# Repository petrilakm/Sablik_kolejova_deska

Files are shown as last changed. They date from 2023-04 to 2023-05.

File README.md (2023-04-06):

# sablik kolejova deska

připojení originální kolejové desky k hJOP pro indikace z modelového kolejiště.
Kolejová deska se chová jako virtuální vyhýbky na sběrnici XpressNET

pro komunikaci s XpressNETem je vytvořena knihovna, která komunikuje
s centrálou jako ovladač LH100.

Panel je jednoúčelový

Control panel for railway switch operation via XpressNET (NX)
tested on Lenz LZV100 and Paco's NanoX. Panel send messages same way as hand controller LH100.
Used microcontroller is ATmega328 (Arduino Nano) and SPI communication with 74HC595 and 74HC165 expanders,
but code can be easily deployed to other AVR family controllers.

On XpressNET there is many virtual switches, which are indicated on real outputs.
Control program (hJOP) sets this virtual switches via python API.

This control panel is only for one purpouse. All changes must be done in source code.

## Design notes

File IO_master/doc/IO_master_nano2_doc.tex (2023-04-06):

\documentclass[a4paper]{report}
\usepackage[landscape]{geometry}
\usepackage{graphicx,color}%,fig}
 \usepackage[czech]{babel}
\setlength{\textheight}{29cm}
\setlength{\textwidth}{20cm}
\pagestyle{empty}
\setlength{\unitlength}{1mm}

%\newcommand{\ram}{
\begin{document}
\begin{picture}(0,0)(50,180)
%\linethickness{0.1pt}
%[angle=90]

%\put(-4,28){\framebox(173,248)}
%\put(-10,10){\mbox{IO\_master -  řídící modul pro kolejovou desku (16. 12. 2022) }}

\put(20,123){}
\put(60,123){}
\put(100,123){}
\put(0,0){}

\end{picture}

\end{document}

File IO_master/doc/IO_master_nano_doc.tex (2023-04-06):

\documentclass[a4paper]{report}
\usepackage{graphicx,color}%,fig}
 \usepackage[czech]{babel}
\setlength{\textheight}{29cm}
\setlength{\textwidth}{20cm}
\pagestyle{empty}
\setlength{\unitlength}{1mm}

%\newcommand{\ram}{
\begin{document}
\begin{picture}(100,140)(23,150)
%\linethickness{0.1pt}
%[angle=90]

%\put(-4,28){\framebox(173,248)}
\put(-10,310){\mbox{IO\_master -  řídící modul pro kolejovou desku (29. 10. 2022) }}
\put(-20,20){}
\put(20,20){}
\put(70,20){}

\end{picture}

\end{document}

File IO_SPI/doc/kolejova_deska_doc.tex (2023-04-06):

\documentclass[a4paper]{report}
%\usepackage{graphicx,color}%,fig}
%\usepackage[czech]{babel}
\usepackage[top=2cm, bottom=2cm, left = 2cm, right = 2cm]{geometry} 
\usepackage{tikz}
%\usepackage{showframe}
%\setlength{\textheight}{29cm}
%\setlength{\textwidth}{18cm}
\setlength{\unitlength}{1mm}
%\title{Kolejová deska}

\begin{document}
kolejová deska Výstupy:

\vspace{7cm}

kolejová deska Vstupy:

\newcommand{\jmi}{RPi_SPI_outputs_v04}
\newcommand{\jmo}{RPi_SPI_inputs_v04}

\vspace{8cm}
\begin{tikzpicture}
%\linethickness{0.1pt}
%[angle=90]
%\put(0,0){\framebox(100,100)}
\put(0,90){}
\put(60,90){}
\put(0,0){}
\put(60,0){}
\end{tikzpicture}
%\end{picture}

Výstupy:

1x 100n 1206

1x 0R 1206

2x DIL16 (75HC595)

3x drátová propojka

\vspace{1cm}

Vstupy:

1x 100n 1206

2x DIL16 (75HC165)

2x rezistorová síť 8x10k

4x drátová propojka

\end{document}

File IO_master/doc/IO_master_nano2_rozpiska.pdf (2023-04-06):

Qty | Value | Parts
1 | | ARDUINO_NANO1
2 | MA08-01 | SV2, SV5
1 | 1N4007-SMD | D1
1 | 47u/25V | C4
1 | 78L05F | IC2
3 | 100n | C1, C2, C3
1 | MAX485 | IC1
1 | WEBP6-6 | J1

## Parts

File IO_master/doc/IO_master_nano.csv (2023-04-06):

Qty | Value | Device | Parts
1 |  | ARDUINO_NANO_2 | ARDUINO_NANO1
2 |  | MA08-1 | SV2, SV5
1 | 1N4007-SMD | 1N4007-SMD | D1
1 | 47u/25V | CPOL-EUE2.5-6L | C4
1 | 78L05F | 78L05F | IC2
3 | 100n | C-EUC1206 | C1, C2, C3
1 | 75176-SO | 75176-SO | IC1
4 | MOUNT-PAD-ROUND3.2 | MOUNT-PAD-ROUND3.2 | H1, H2, H3, H4
1 | WEBP6-6_SPEC2 | WEBP6-6_SPEC2 | J1

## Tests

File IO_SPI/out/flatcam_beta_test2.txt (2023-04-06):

; load
open_gerber z:\petrilak.m\Elektronika\Projekty\KMZ\Doplnky\Sablik_kolejova_deska\IO_SPI\brd\RPi_SPI_inputs_v04.bot.grb -outname bot
set_sys excellon_zeros T
open_excellon z:\petrilak.m\Elektronika\Projekty\KMZ\Doplnky\Sablik_kolejova_deska\IO_SPI\brd\RPi_SPI_inputs_v04.exc  -outname drl
plot_all

; export etch
isolate bot -dia 0.22 -passes 3 -overlap 30 -combine 1 -outname iso
cncjob iso -z_cut -0.08 -z_move 1.2 -feedrate 240 -feedrate_z 120 -dia 0.2 -spindlespeed 30000 -outname etch
write_gcode etch z:/petrilak.m/Elektronika/Projekty/KMZ/Doplnky/Sablik_kolejova_deska/IO_SPI/out/inputs_v04_etch.nc

; export drill
drillcncjob drl -drillz -3 -travelz 1 -feedrate_z 200 -toolchangez 15.0 -endxy (-20.0,20.0) -toolchangexy (-20.0,20.0) -dwelltime 0.1 -diatol 5 -outname drills

; export outline
open_gerber z:\\petrilak.m\\Elektronika\\Projekty\\KMZ\\Doplnky\\Sablik_kolejova_deska\\IO_SPI\\brd\\RPi_SPI_inputs_v04.out.grb -outname outline
follow outline -outname outline_geo
cutout outline_geo -dia 2.0 -margin 0.1 -gapsize 0.5 -gaps lr -outname out_cnc
cncjob out_cnc -z_cut -2.0 -dpp 0.7 -z_move 1.2 -feedrate 100 -feedrate_z 60 -dia 2 -spindlespeed 30000 -outname out
write_gcode out z:/petrilak.m/Elektronika/Projekty/KMZ/Doplnky/Sablik_kolejova_deska/IO_SPI/out/inputs_v04_out.nc

interiors
milldrills drl -milled_dias "3.2" -tooldia 2.0 -diatol 50 -outname drlmill

millholes drl -tools 5 -tooldia 2.0 -outname drlmill
cutout bot -dia 2.0 -margin 0.1 -gapsize 0.5 -gaps 4

drillcncjob
cncjob iso
cncjob iso

// merge
new
set_sys excellon_zeros T
open_excellon z:/petrilak.m/Elektronika/Projekty/KMZ/Doplnky/Sablik_kolejova_deska/IO_SPI/brd/RPi_SPI_outputs_v04.txt -outname drl1
open_excellon z:/petrilak.m/Elektronika/Projekty/KMZ/Doplnky/Sablik_kolejova_deska/IO_SPI/brd/RPi_SPI_outputs_v04.txt -outname drl2
offset drl2 0 44
join_excellons drl drl1 drl2

open_gerber z:/petrilak.m/Elektronika/Projekty/KMZ/Doplnky/Sablik_kolejova_deska/IO_SPI/brd/RPi_SPI_outputs_v04.bot -outname bot1
open_gerber z:/petrilak.m/Elektronika/Projekty/KMZ/Doplnky/Sablik_kolejova_deska/IO_SPI/brd/RPi_SPI_outputs_v04.bot -outname bot2
offset bot2 0 44

open_gerber z:/petrilak.m/Elektronika/Projekty/KMZ/Doplnky/Sablik_kolejova_deska/IO_SPI/brd/RPi_SPI_outputs_v04.out -outname outline1
open_gerber z:/petrilak.m/Elektronika/Projekty/KMZ/Doplnky/Sablik_kolejova_deska/IO_SPI/brd/RPi_SPI_outputs_v04.out -outname outline2
offset outline2 0 44
follow outline1 -outname outline_geo1
follow outline2 -outname outline_geo2
join_geometry outline outline_geo1 outline_geo2 
cncjob outline -z_cut -2.6 -z_move 1.2 -feedrate 100 -feedrate_z 60 -dia 2 -spindlespeed 30000 -outname holes

isolate bot1 -dia 0.18 -passes 4 -overlap 5 -combine 1 -outname iso1
isolate bot2 -dia 0.18 -passes 4 -overlap 5 -combine 1 -outname iso2
join_geometries iso iso1 iso2

milldrills drl -milled_dias 3.2 -tooldia 2.0 -diatol 50 -outname drlmill
millholes drl -tooldia 2.0 -outname drlmill

cutout outline_geo -dia 2.0 -margin 0.1 -gapsize 0.5 -gaps lr -outname out1
cutout outline_geo2 -dia 2.0 -margin 0.1 -gapsize 0.5 -gaps lr -outname out2
join_geometry out out1 out2
cncjob out -z_cut -2.6 -z_move 1.2 -endz 10.0 -feedrate 100 -feedrate_z 60 -dia 2 -spindlespeed 30000 -dpp 0.7 -outname outa
write_gcode out z:/petrilak.m/Elektronika/Projekty/KMZ/Doplnky/Sablik_kolejova_deska/IO_SPI/out/out.nc

drillcncjob drl -drillz -3 -travelz 1 -feedrate_z 200 -toolchangez 15.0 -endxy (20.0,-20.0) -dwelltime 0.1 -diatol 5 -outname drills
cncjob iso -z_cut -0.08 -z_move 1.2 -feedrate 240 -feedrate_z 120 -dia 0.2 -spindlespeed 30000 -outname etch
write_gcode etch z:/petrilak.m/Elektronika/Projekty/KMZ/Doplnky/Sablik_kolejova_deska/IO_SPI/out/etch.nc
write_gcode drills z:/petrilak.m/Elektronika/Projekty/KMZ/Doplnky/Sablik_kolejova_deska/IO_SPI/out/drills.nc
write_gcode drl_cnc z:/petrilak.m/Elektronika/Projekty/KMZ/Doplnky/Sablik_kolejova_deska/IO_SPI/out/drills.nc

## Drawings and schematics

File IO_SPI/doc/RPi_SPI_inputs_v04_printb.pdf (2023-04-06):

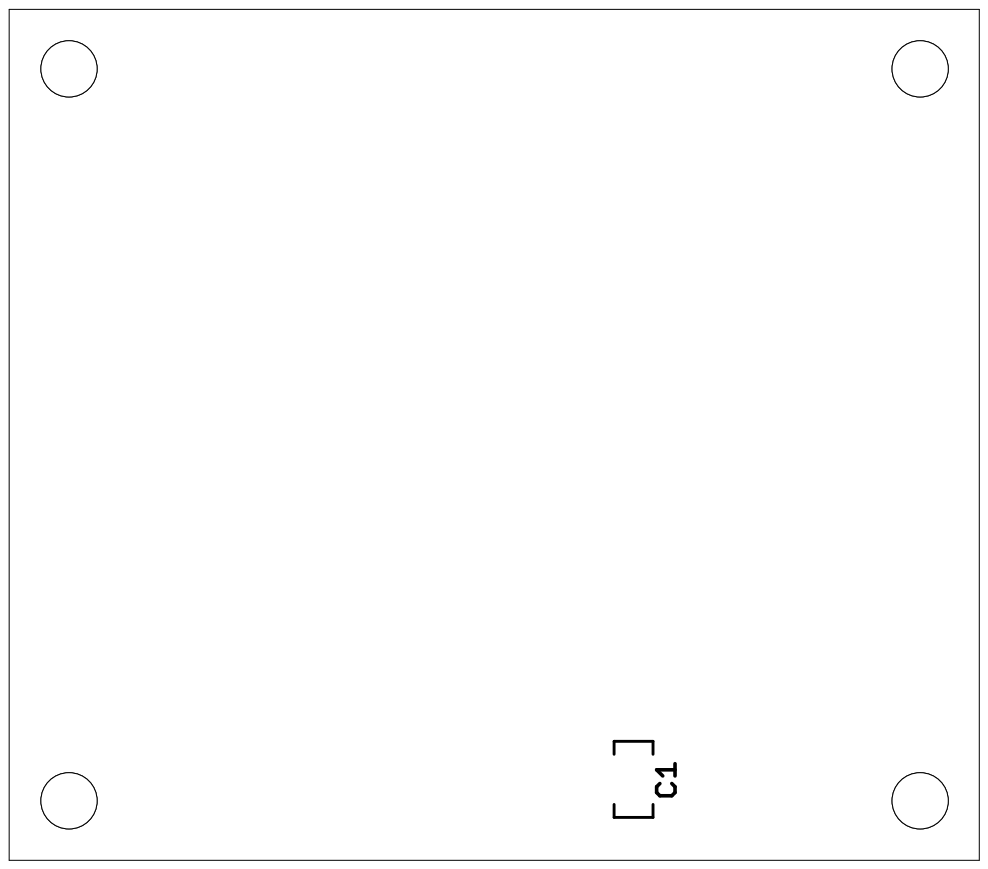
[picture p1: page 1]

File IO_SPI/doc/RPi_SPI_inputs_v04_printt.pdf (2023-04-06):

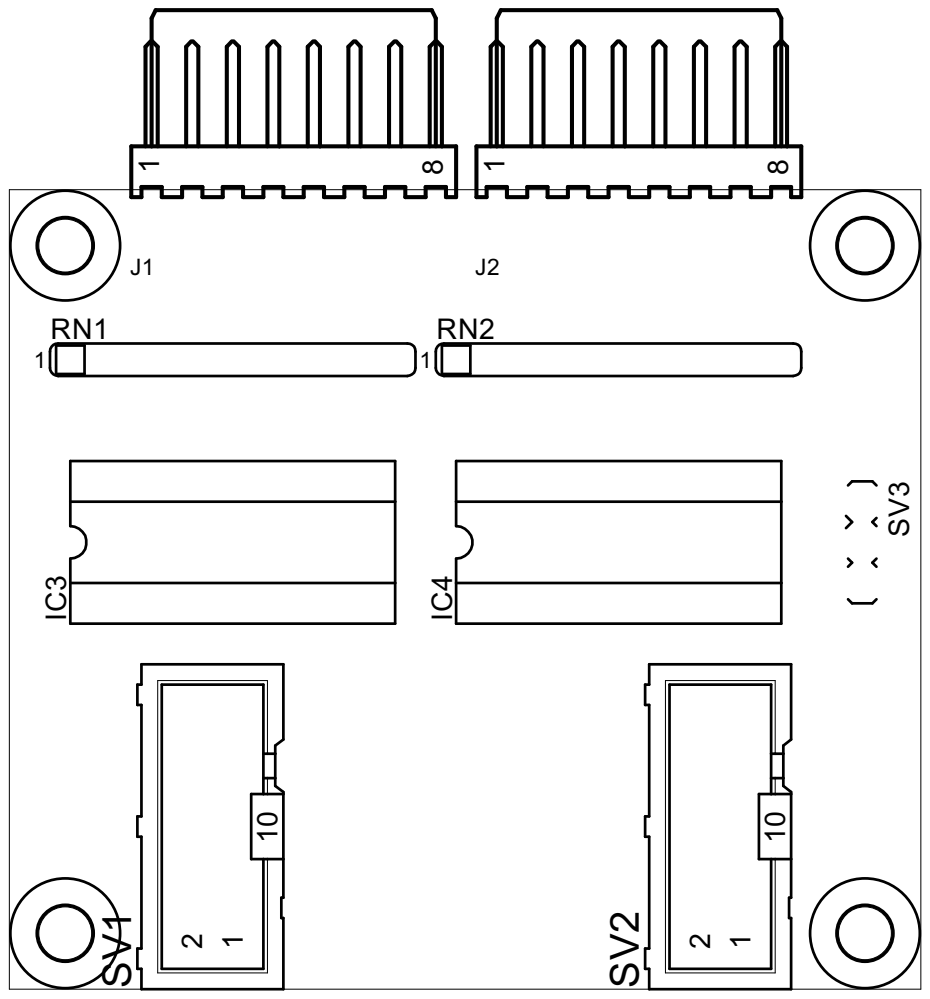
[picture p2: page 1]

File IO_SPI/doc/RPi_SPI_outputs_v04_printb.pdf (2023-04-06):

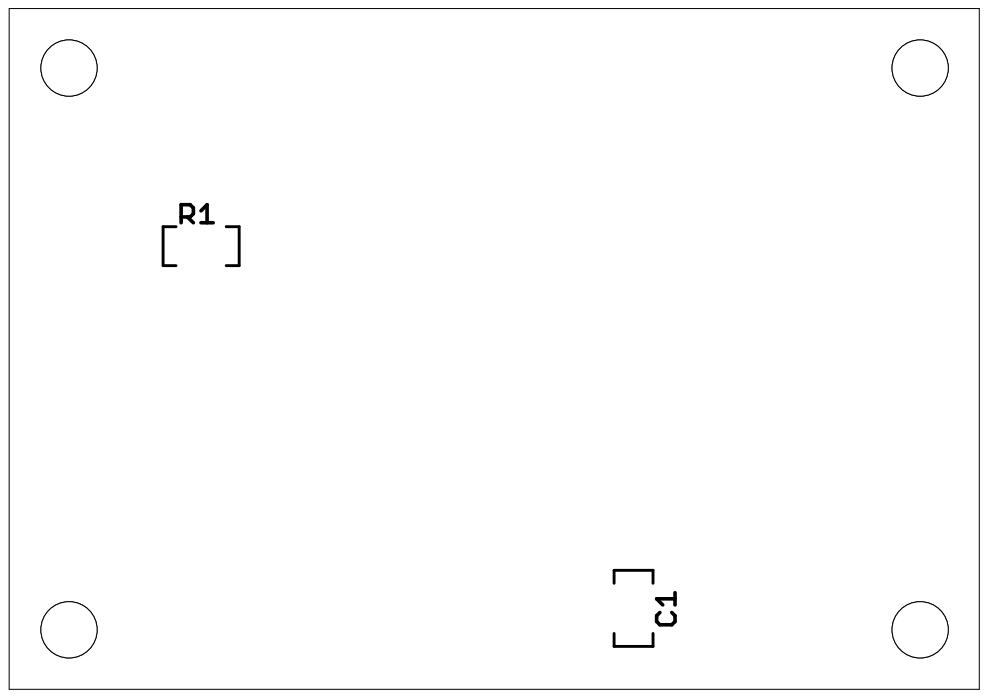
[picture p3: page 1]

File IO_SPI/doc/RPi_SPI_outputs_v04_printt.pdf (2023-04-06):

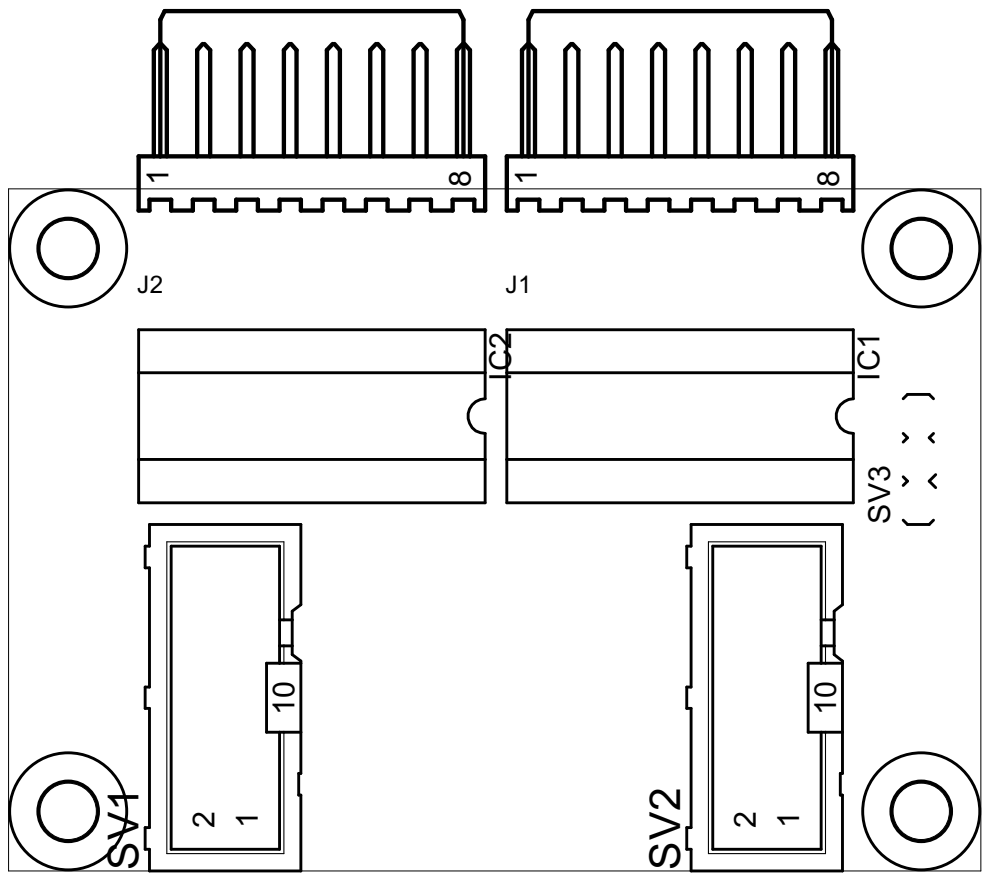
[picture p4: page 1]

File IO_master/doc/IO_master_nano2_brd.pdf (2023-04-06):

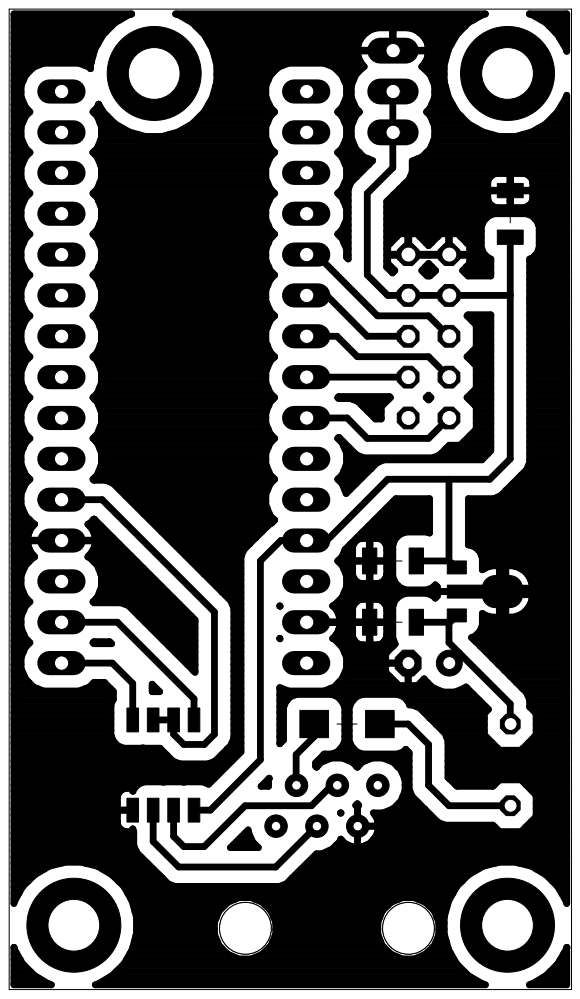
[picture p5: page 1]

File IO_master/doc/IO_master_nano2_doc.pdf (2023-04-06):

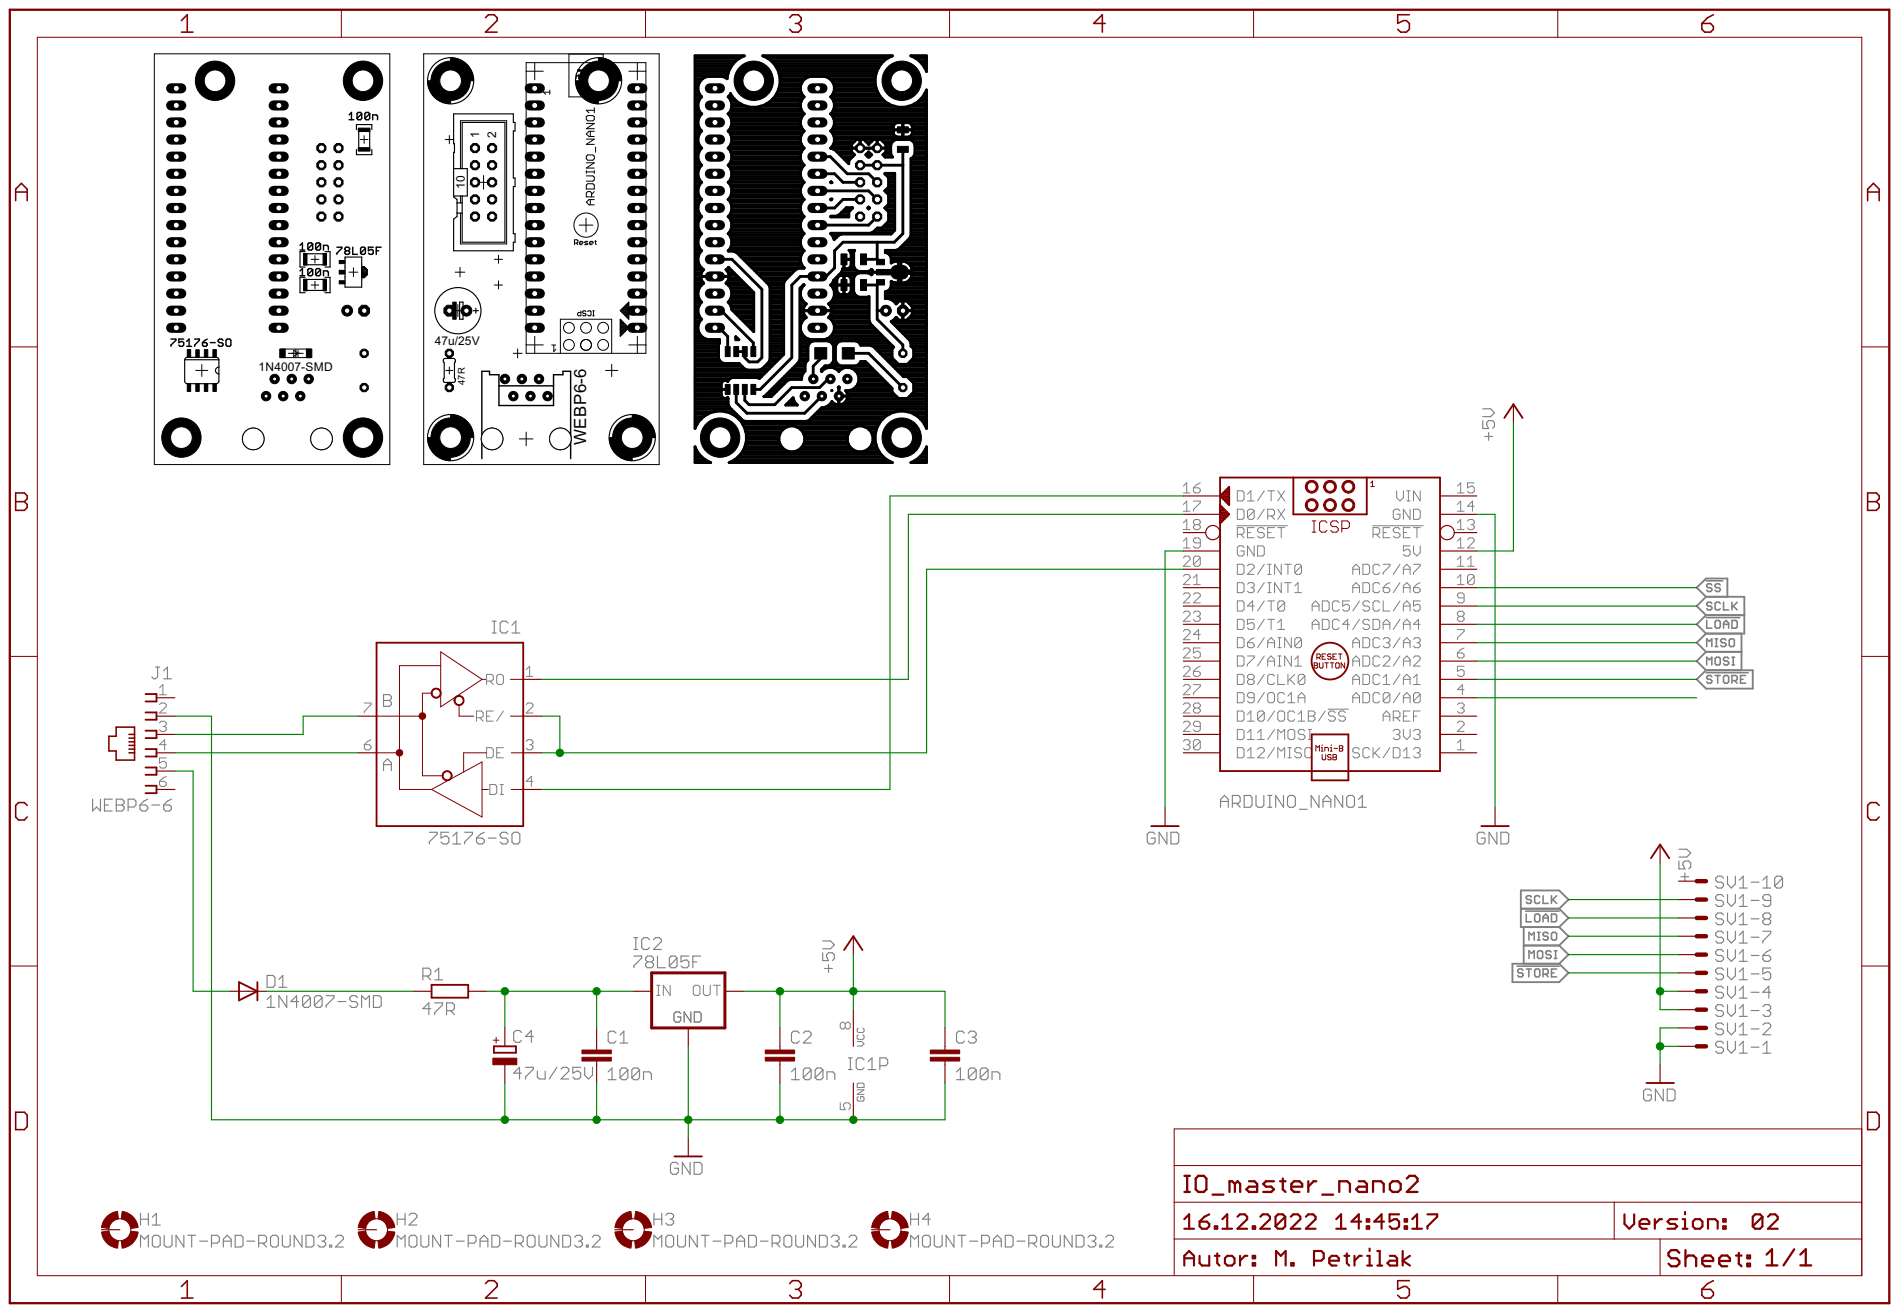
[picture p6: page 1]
1N4007-SMD; WEBP⁶⁻⁶

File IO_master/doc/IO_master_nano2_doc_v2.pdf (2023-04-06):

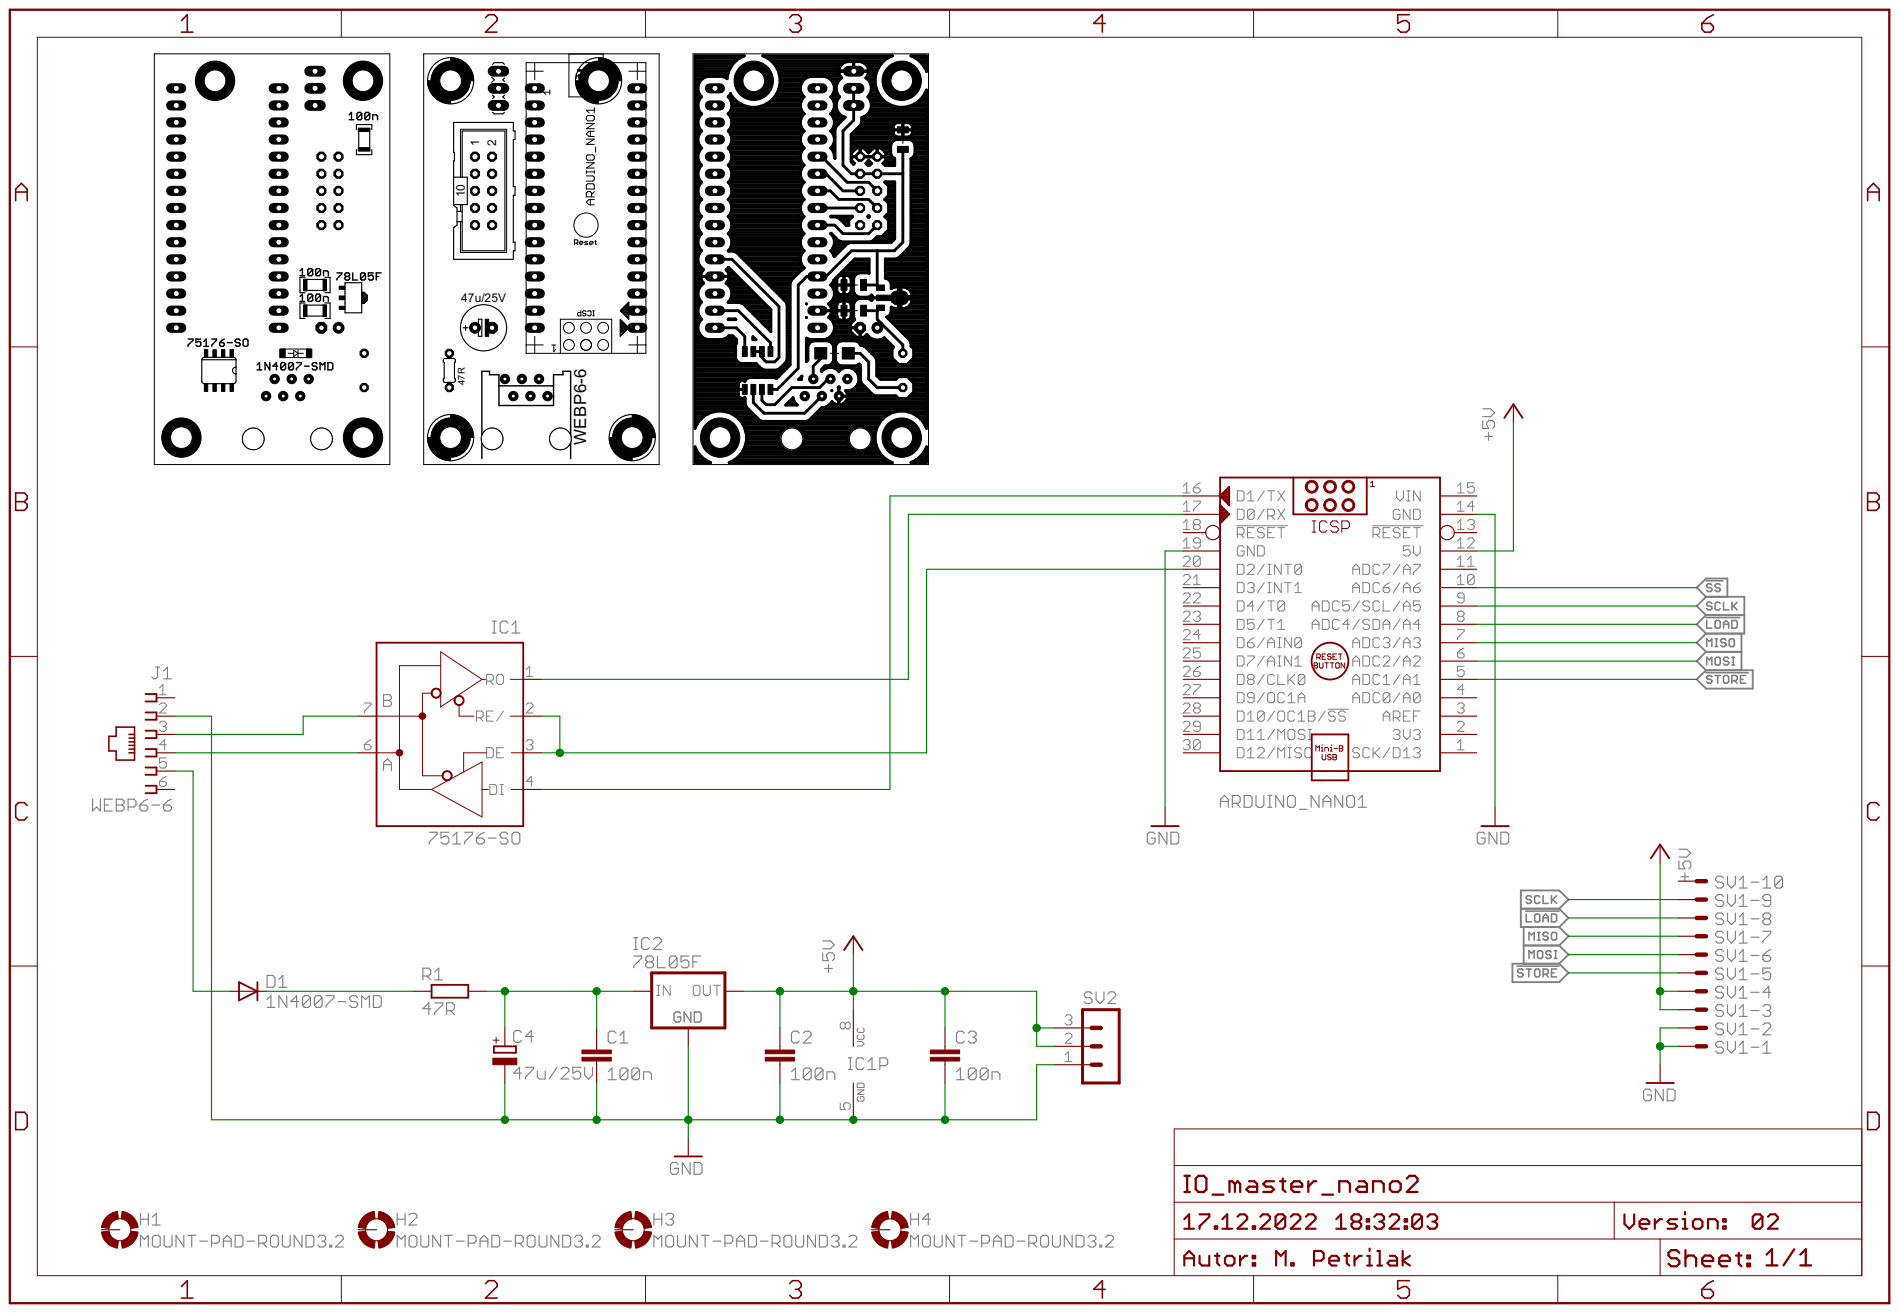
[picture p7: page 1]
WEBP⁶⁻⁶

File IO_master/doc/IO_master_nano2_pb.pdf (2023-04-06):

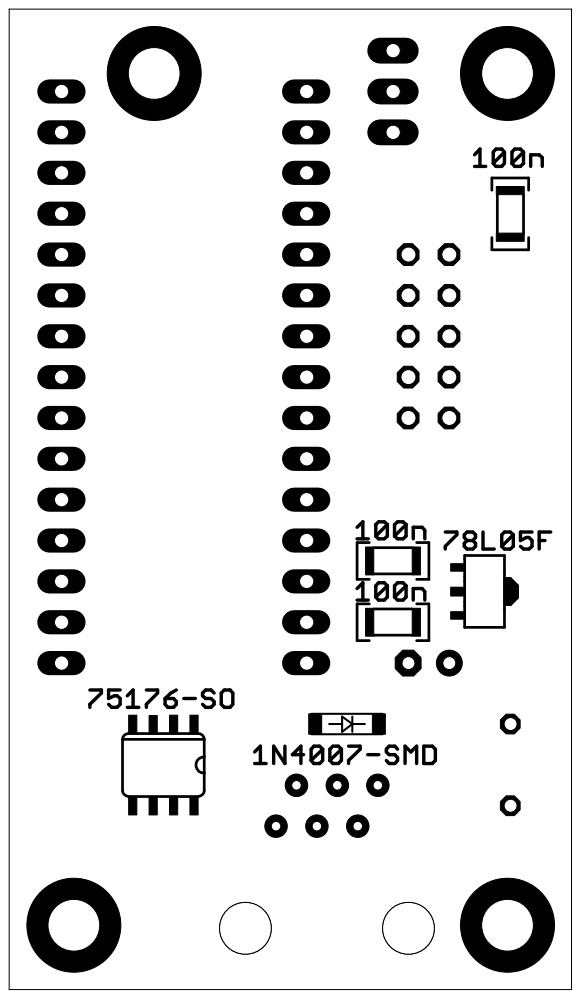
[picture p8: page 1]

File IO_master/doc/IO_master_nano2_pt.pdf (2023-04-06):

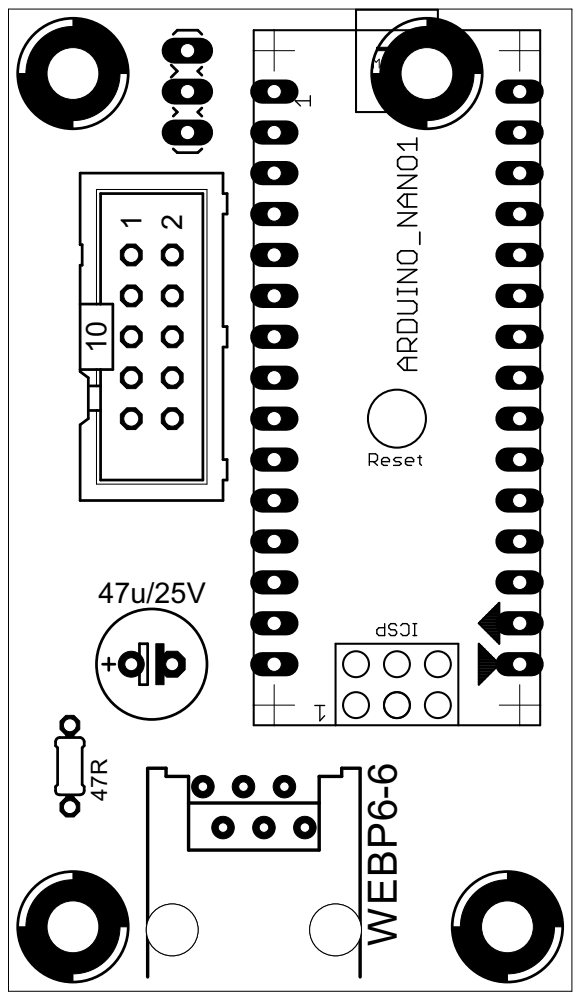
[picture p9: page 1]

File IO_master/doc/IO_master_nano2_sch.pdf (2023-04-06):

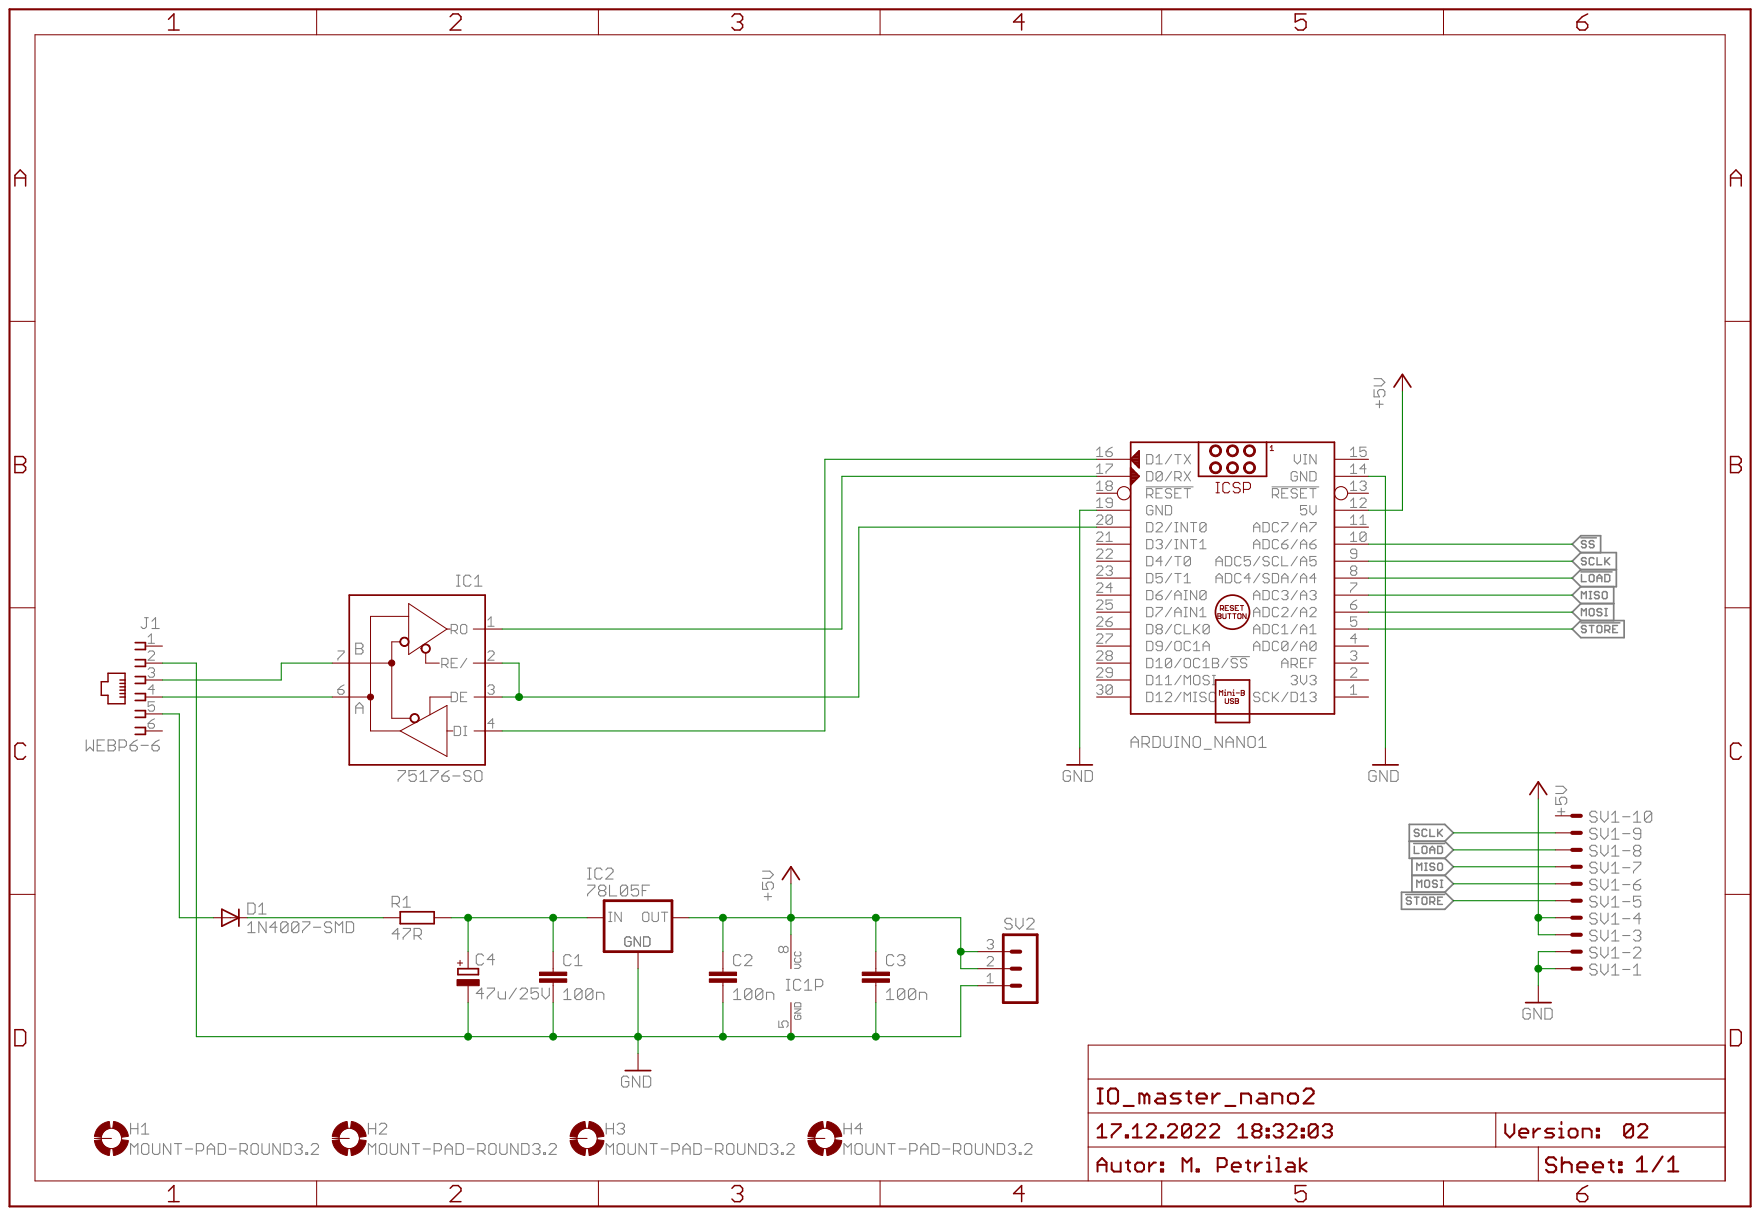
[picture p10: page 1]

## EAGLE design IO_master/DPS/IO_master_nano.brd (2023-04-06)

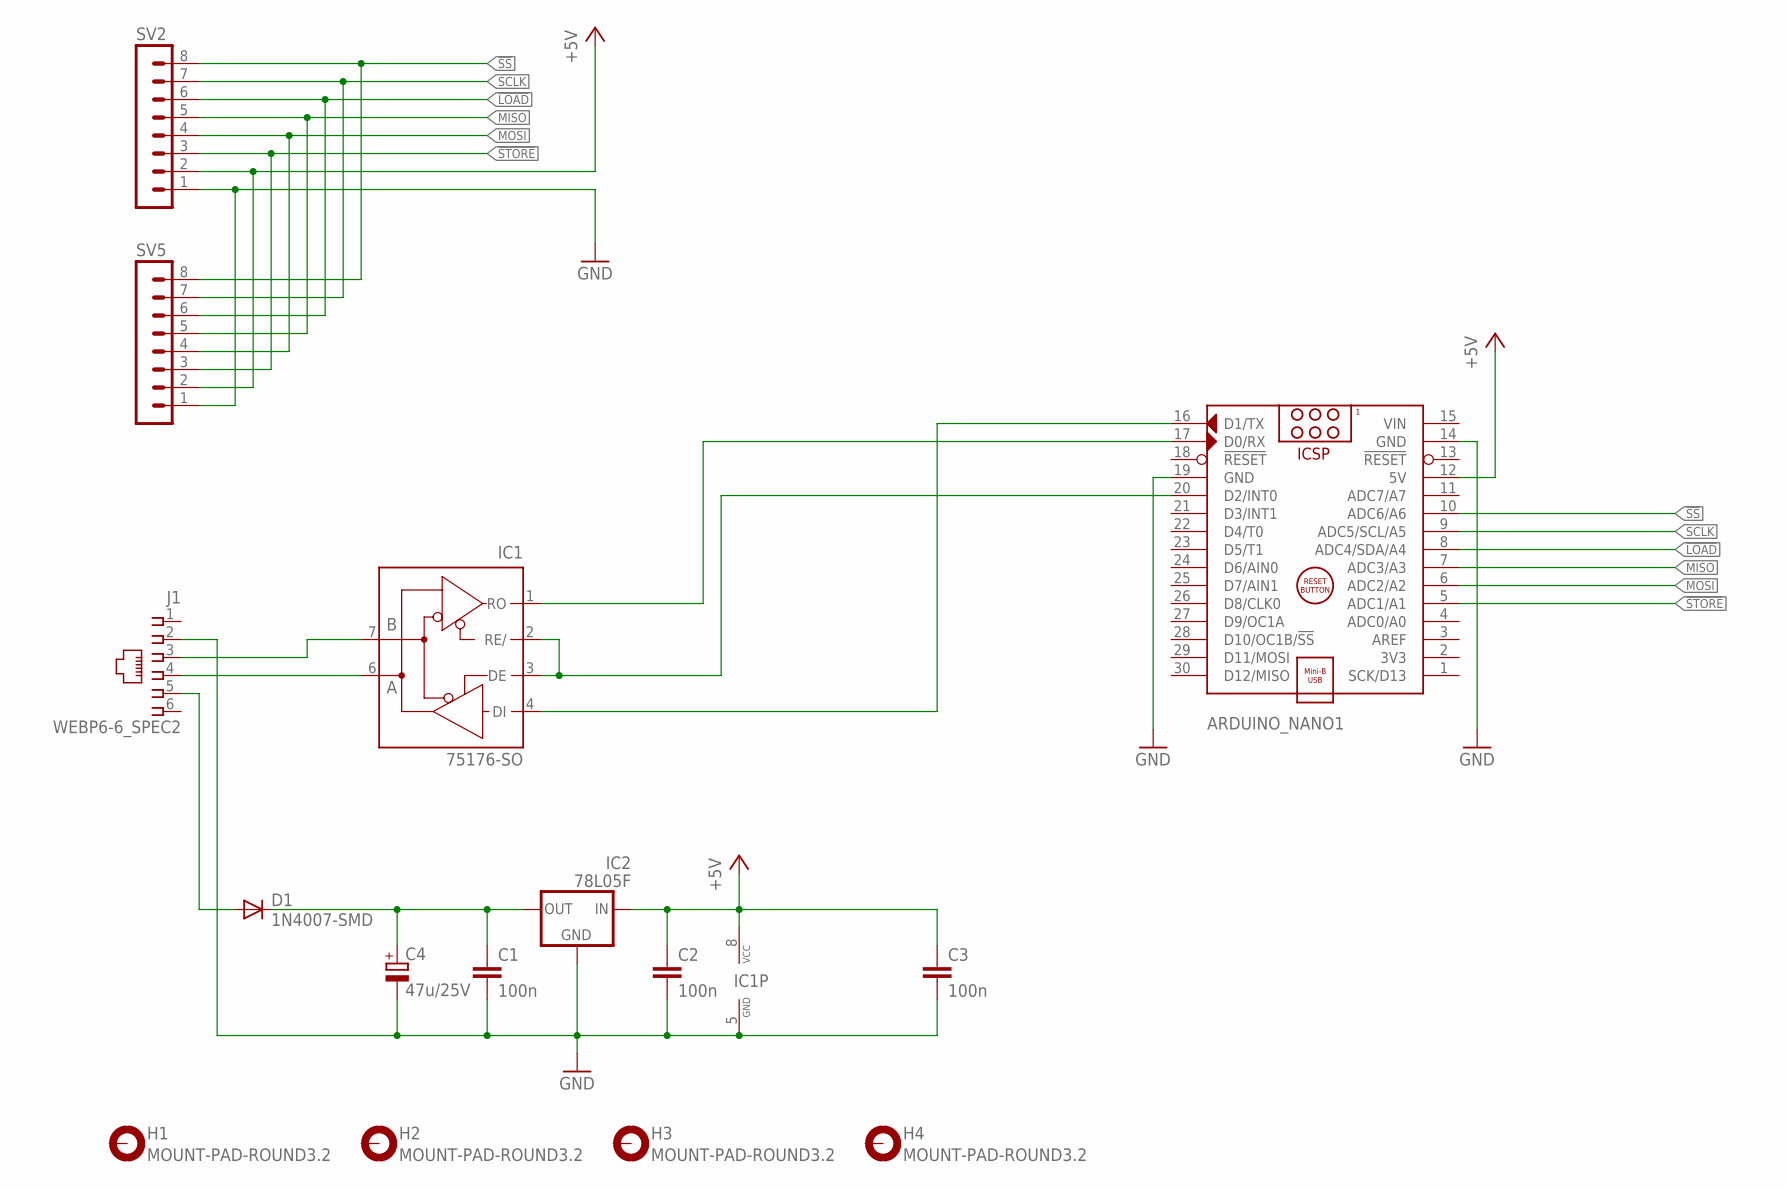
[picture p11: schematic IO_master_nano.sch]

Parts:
ARDUINO_NANO1: ARDUINO_NANO_2; ARDUINO_NANO2
C1, C2, C3: 100n; C1206
C4: 47u/25V; E2,5-6L
D1: 1N4007-SMD; SMA-DO214AC
H1, H2, H3, H4: MOUNT-PAD-ROUND3.2; 3,2-PAD
IC1: 75176-SO; SO08
IC2: 78L05F; SOT89
J1: WEBP6-6_SPEC2
SV2, SV5: MA08-1

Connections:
!LOAD: ARDUINO_NANO1.8 (ADC4/SDA/A4), SV2.6, SV5.6
!SS: ARDUINO_NANO1.10 (ADC6/A6), SV2.8, SV5.8
!STORE: ARDUINO_NANO1.5 (ADC1/A1), SV2.3, SV5.3
+5V: ARDUINO_NANO1.12 (5V), C2.1, C3.1, IC1.8 (VCC), IC2.3 (VI), SV2.2, SV5.2
GND: ARDUINO_NANO1.14 (GND), ARDUINO_NANO1.19 (GND), C1.2, C2.2, C3.2, C4.-, IC1.5 (GND), IC2.2 (GND), IC2.2@1 (GND), J1.2, SV2.1, SV5.1
MISO: ARDUINO_NANO1.7 (ADC3/A3), SV2.5, SV5.5
MOSI: ARDUINO_NANO1.6 (ADC2/A2), SV2.4, SV5.4
unnamed: D1.A, J1.5
unnamed: C1.1, C4.+, D1.K (C), IC2.1 (VO)
unnamed: IC1.6 (A), J1.4
unnamed: IC1.7 (B), J1.3
unnamed: ARDUINO_NANO1.20 (D2/INT0), IC1.2 (RE/), IC1.3 (DE)
unnamed: ARDUINO_NANO1.16 (D1/TX), IC1.4 (DI)
unnamed: ARDUINO_NANO1.17 (D0/RX), IC1.1 (RO)
SCLK: ARDUINO_NANO1.9 (ADC5/SCL/A5), SV2.7, SV5.7
VIN: ARDUINO_NANO1.15 (VIN)

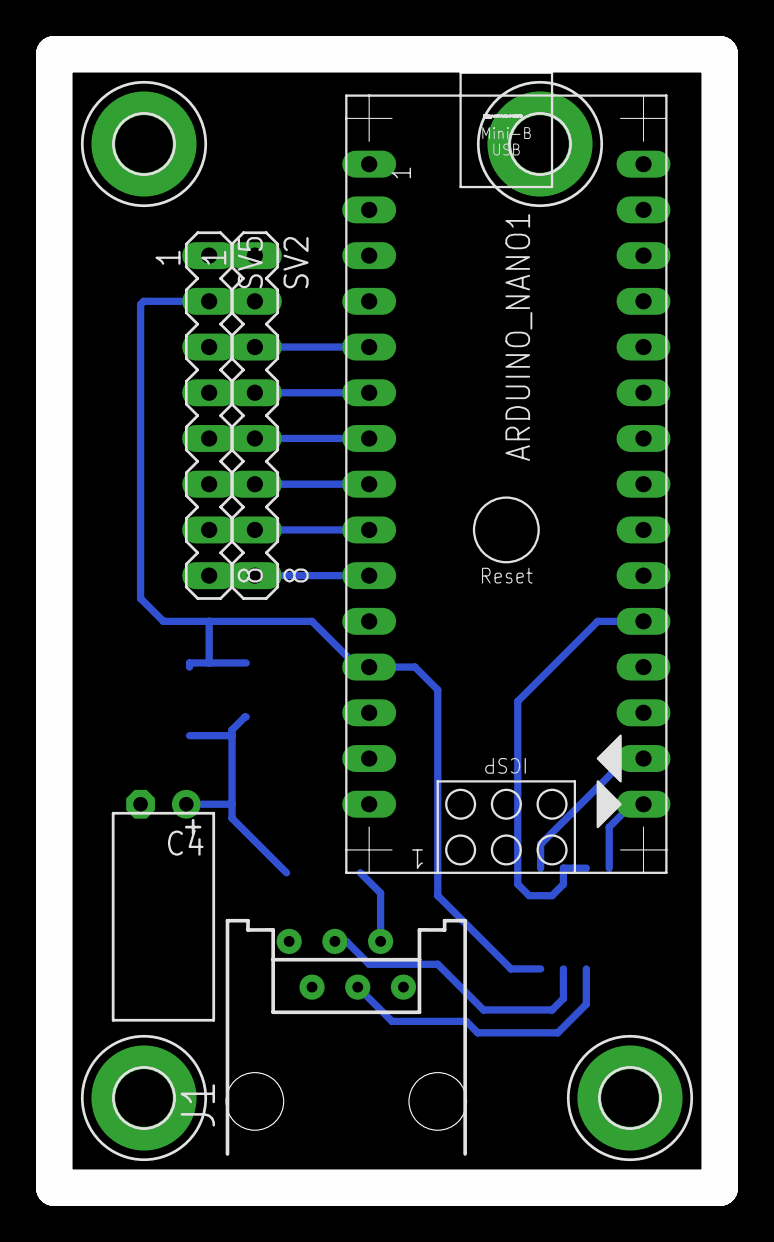
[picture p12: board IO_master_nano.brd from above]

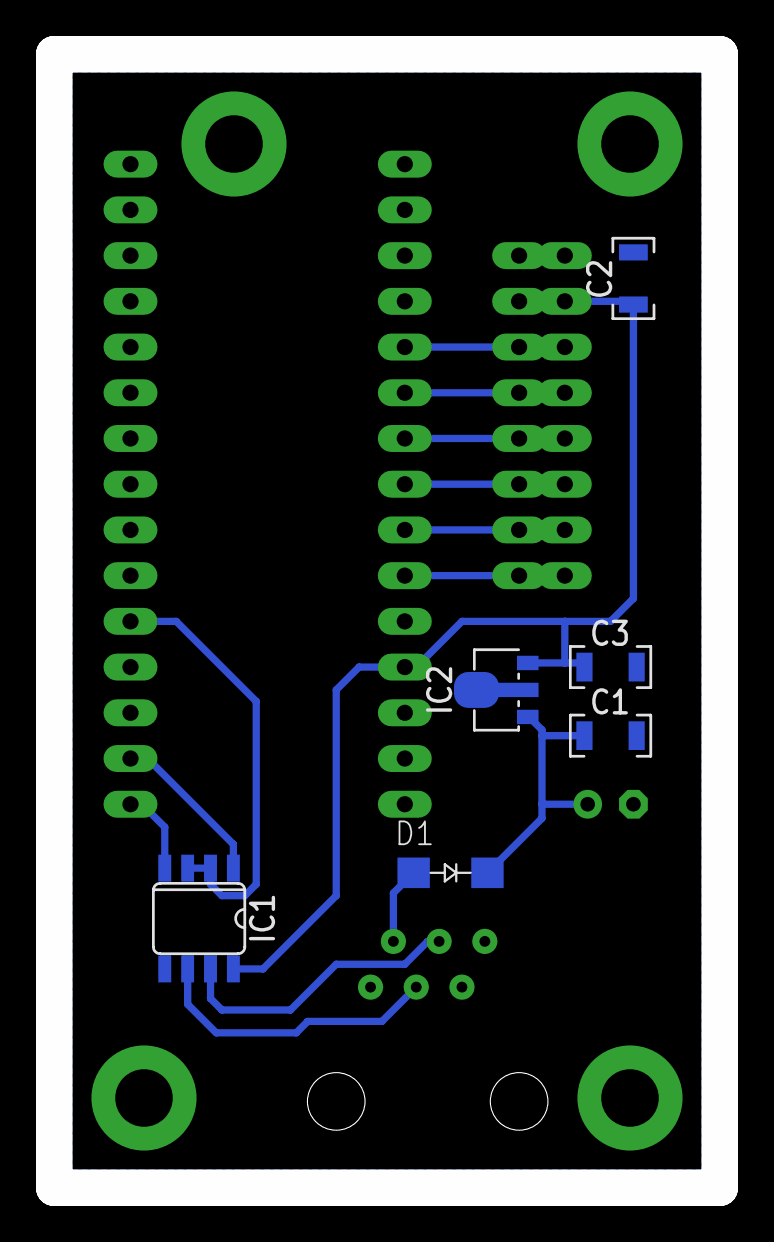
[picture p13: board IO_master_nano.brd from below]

Board: 2 copper layers, 37.0 x 63.0 mm, 15 parts (6 on the bottom side), 15 nets.

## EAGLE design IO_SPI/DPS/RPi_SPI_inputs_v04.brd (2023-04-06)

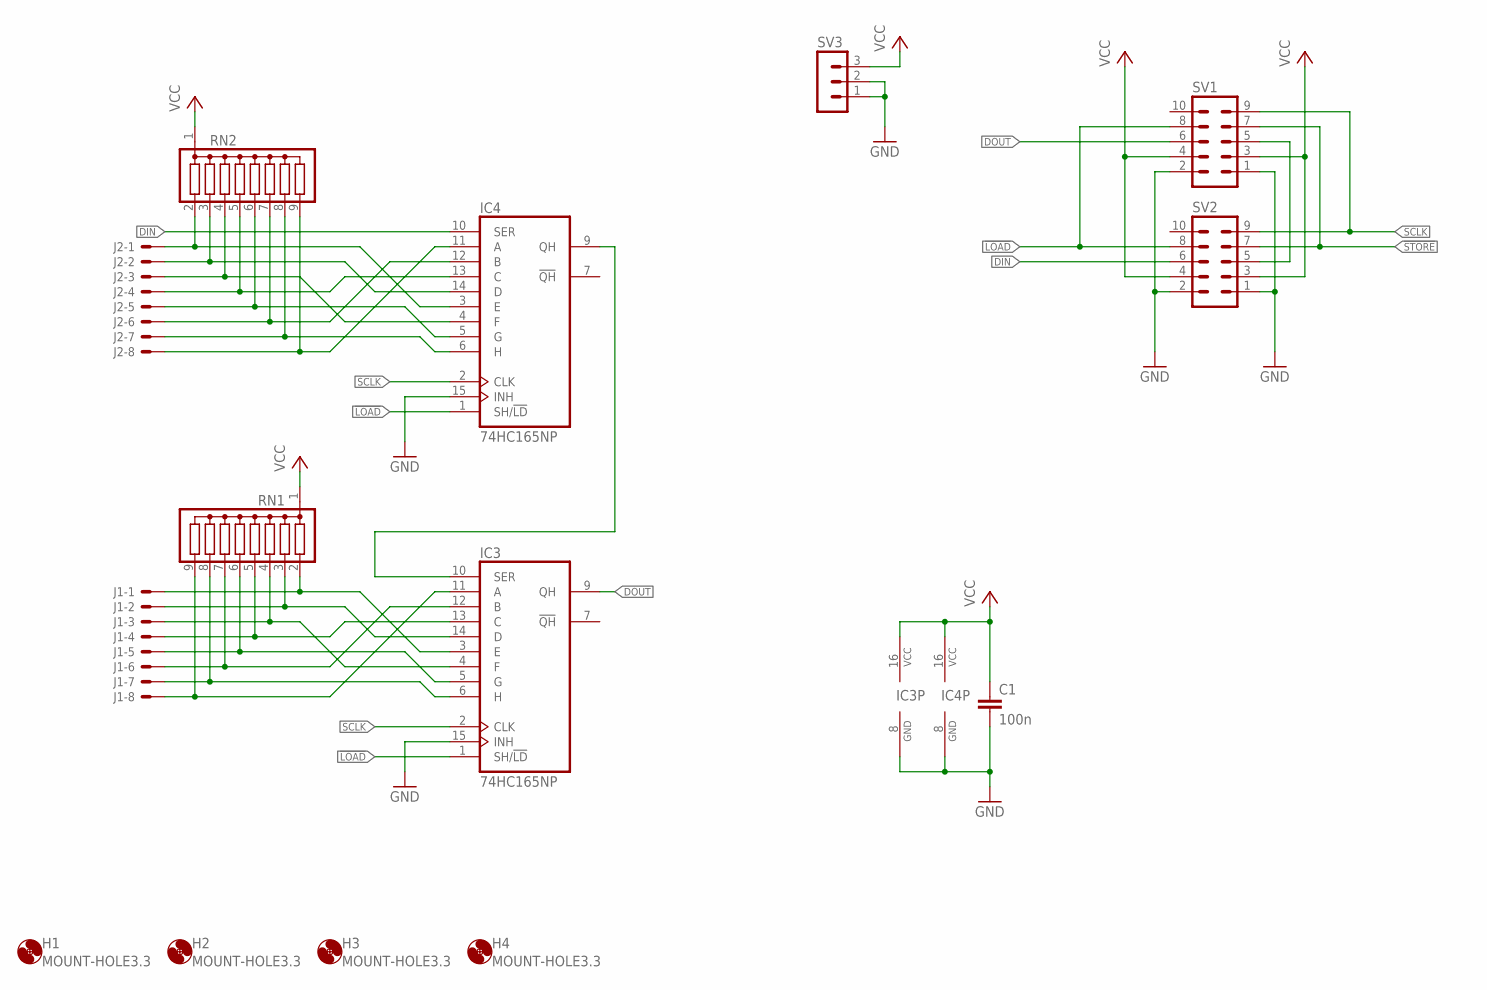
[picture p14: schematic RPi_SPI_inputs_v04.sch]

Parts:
C1: 100n; C1206
H1, H2, H3, H4: MOUNT-HOLE3.3; 3,3
IC3, IC4: 74HC165NP; SOCKET-16
J1, J2: 22-05-7088-SPEC-08; 7395-08_SPEC
RN1, RN2: G08R; SIL9
SV1, SV2: ML10
SV3: MA03-1_NO

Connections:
!LOAD: IC3.1 (SH/!LD), IC4.1 (SH/!LD), SV1.8, SV2.8
!STORE: SV1.7, SV2.7
DIN: IC4.10 (SER), SV2.6
DOUT: IC3.9 (QH), SV1.6
DRET: SV1.5, SV2.5
GND: C1.2, IC3.8 (GND), IC3.15 (INH), IC4.8 (GND), IC4.15 (INH), SV1.1, SV1.2, SV2.1, SV2.2, SV3.1, SV3.2
unnamed: IC4.11 (A), J2.8, RN2.9
unnamed: IC4.6 (H), J2.7, RN2.8
unnamed: IC3.10 (SER), IC4.9 (QH)
unnamed: IC4.12 (B), J2.6, RN2.7
unnamed: IC4.5 (G), J2.5, RN2.6
unnamed: IC4.13 (C), J2.4, RN2.5
unnamed: IC4.4 (F), J2.3, RN2.4
unnamed: IC4.14 (D), J2.2, RN2.3
unnamed: IC4.3 (E), J2.1, RN2.2
unnamed: IC3.3 (E), J1.1, RN1.2
unnamed: IC3.14 (D), J1.2, RN1.3
unnamed: IC3.4 (F), J1.3, RN1.4
unnamed: IC3.13 (C), J1.4, RN1.5
unnamed: IC3.5 (G), J1.5, RN1.6
unnamed: IC3.12 (B), J1.6, RN1.7
unnamed: IC3.6 (H), J1.7, RN1.8
unnamed: IC3.11 (A), J1.8, RN1.9
SCLK: IC3.2 (CLK), IC4.2 (CLK), SV1.9, SV2.9
VCC: C1.1, IC3.16 (VCC), IC4.16 (VCC), RN1.1, RN2.1, SV1.3, SV1.4, SV2.3, SV2.4, SV3.3

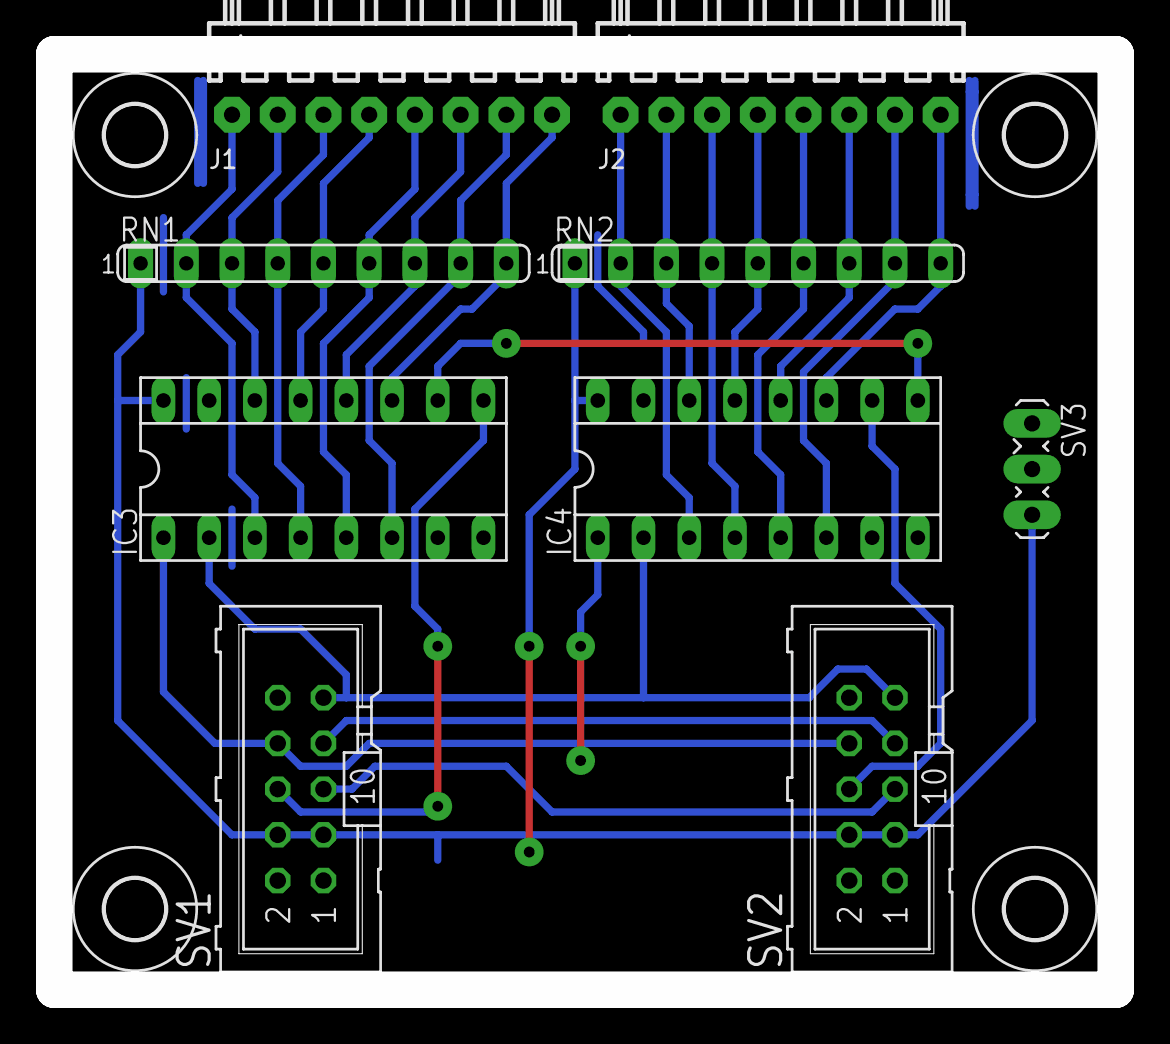
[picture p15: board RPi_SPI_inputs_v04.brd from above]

Board: 2 copper layers, 59.0 x 52.0 mm, 14 parts (1 on the bottom side), 25 nets.

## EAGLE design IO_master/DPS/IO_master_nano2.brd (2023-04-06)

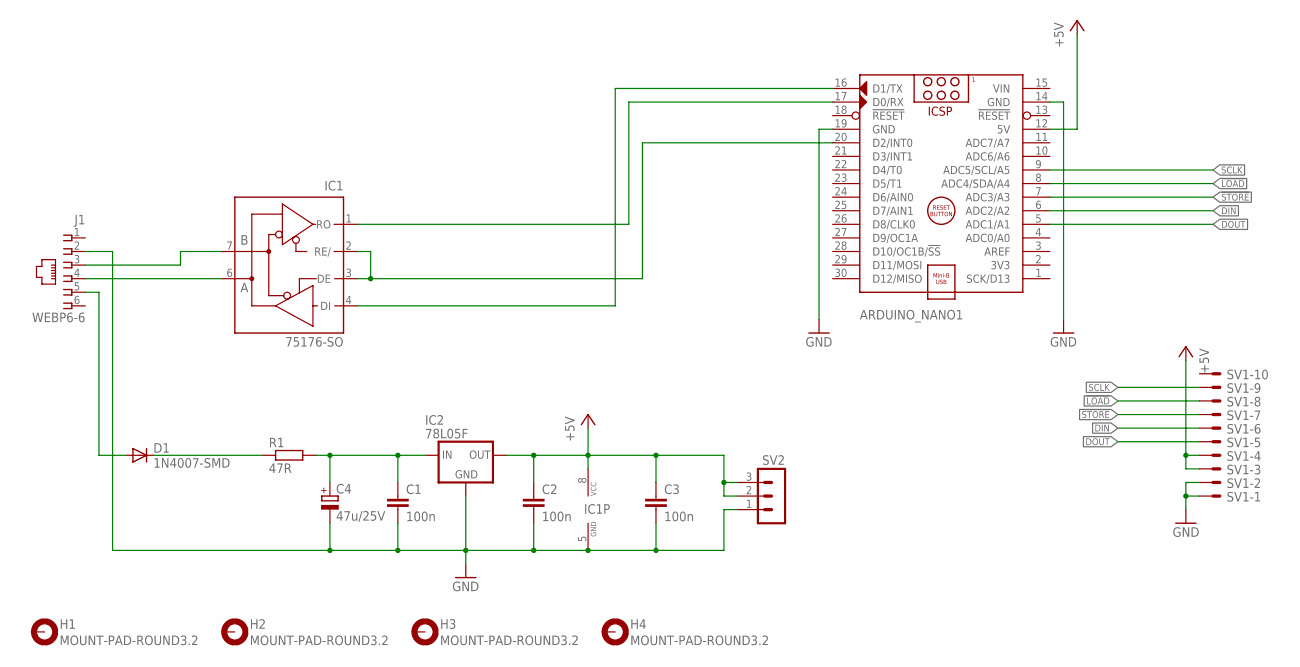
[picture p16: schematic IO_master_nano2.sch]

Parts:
ARDUINO_NANO1: ARDUINO_NANO_2; ARDUINO_NANO2
C1, C2, C3: 100n; C1206
C4: 47u/25V; E2,5-7
D1: 1N4007-SMD; SMA-DO214AC
H1, H2, H3, H4: MOUNT-PAD-ROUND3.2; 3,2-PAD
IC1: 75176-SO; SO08
IC2: 78L05F; SOT89
J1: WEBP6-6; WEBP6-6_SPEC2
R1: 47R; 0204/5
SV1: ML10E; ML10
SV2: MA03-1_NO

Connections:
!LOAD: ARDUINO_NANO1.8 (ADC4/SDA/A4), SV1.8
!STORE: ARDUINO_NANO1.7 (ADC3/A3), SV1.7
+5V: ARDUINO_NANO1.12 (5V), C2.1, C3.1, IC1.8 (VCC), IC2.1 (VO), SV1.3, SV1.4, SV2.2, SV2.3
DIN: ARDUINO_NANO1.6 (ADC2/A2), SV1.6
DOUT: ARDUINO_NANO1.5 (ADC1/A1), SV1.5
GND: ARDUINO_NANO1.14 (GND), ARDUINO_NANO1.19 (GND), C1.2, C2.2, C3.2, C4.-, IC1.5 (GND), IC2.2 (GND), IC2.2@1 (GND), J1.2, SV1.1, SV1.2, SV2.1
unnamed: D1.A, J1.5
unnamed: C1.1, C4.+, IC2.3 (VI), R1.2
unnamed: D1.K (C), R1.1
unnamed: IC1.6 (A), J1.4
unnamed: IC1.7 (B), J1.3
unnamed: ARDUINO_NANO1.20 (D2/INT0), IC1.2 (RE/), IC1.3 (DE)
unnamed: ARDUINO_NANO1.16 (D1/TX), IC1.4 (DI)
unnamed: ARDUINO_NANO1.17 (D0/RX), IC1.1 (RO)
SCLK: ARDUINO_NANO1.9 (ADC5/SCL/A5), SV1.9
VIN: ARDUINO_NANO1.15 (VIN)

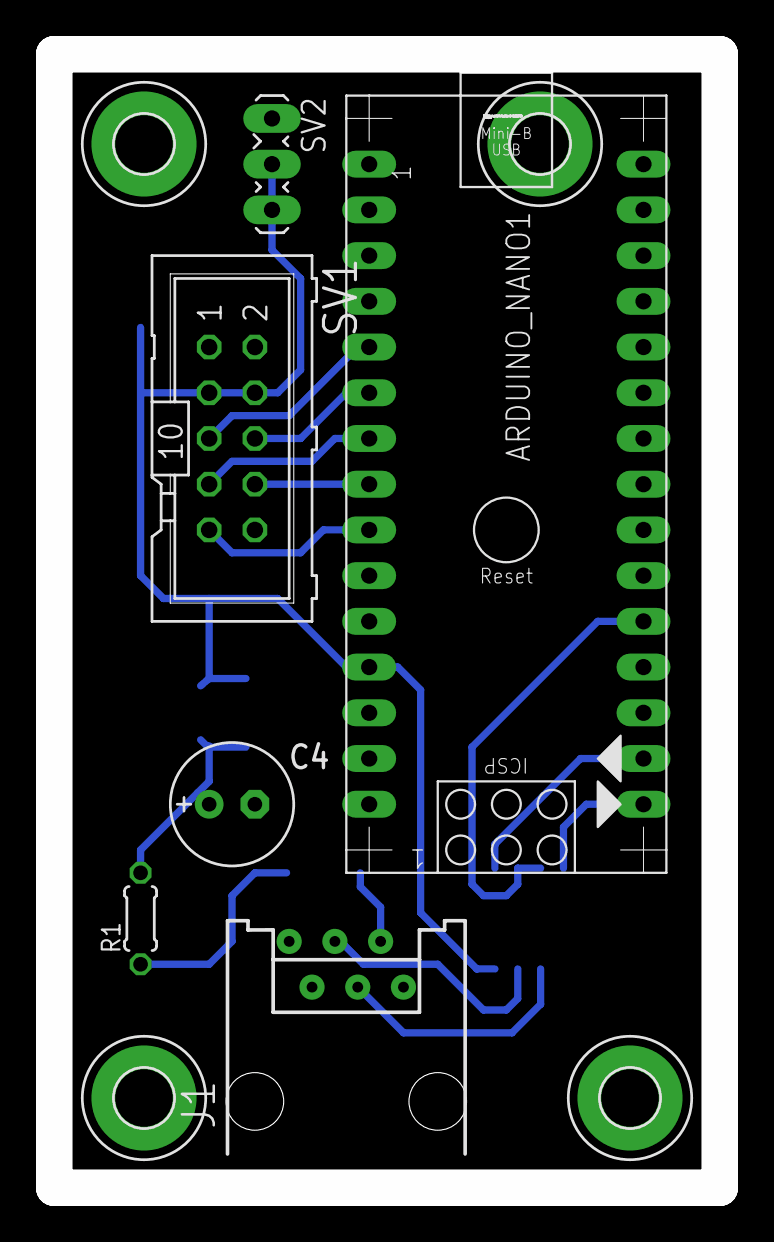
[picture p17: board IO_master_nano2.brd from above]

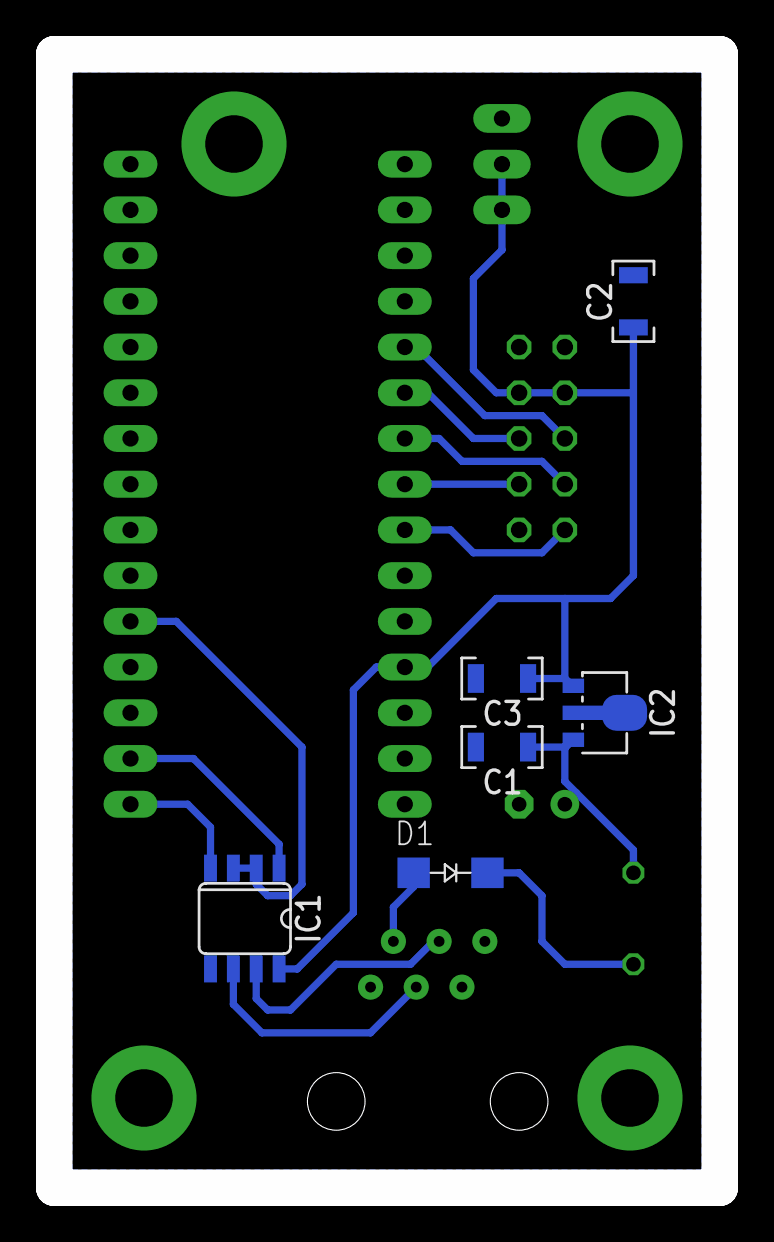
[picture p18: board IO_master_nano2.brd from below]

Board: 2 copper layers, 37.0 x 63.0 mm, 16 parts (6 on the bottom side), 15 nets.

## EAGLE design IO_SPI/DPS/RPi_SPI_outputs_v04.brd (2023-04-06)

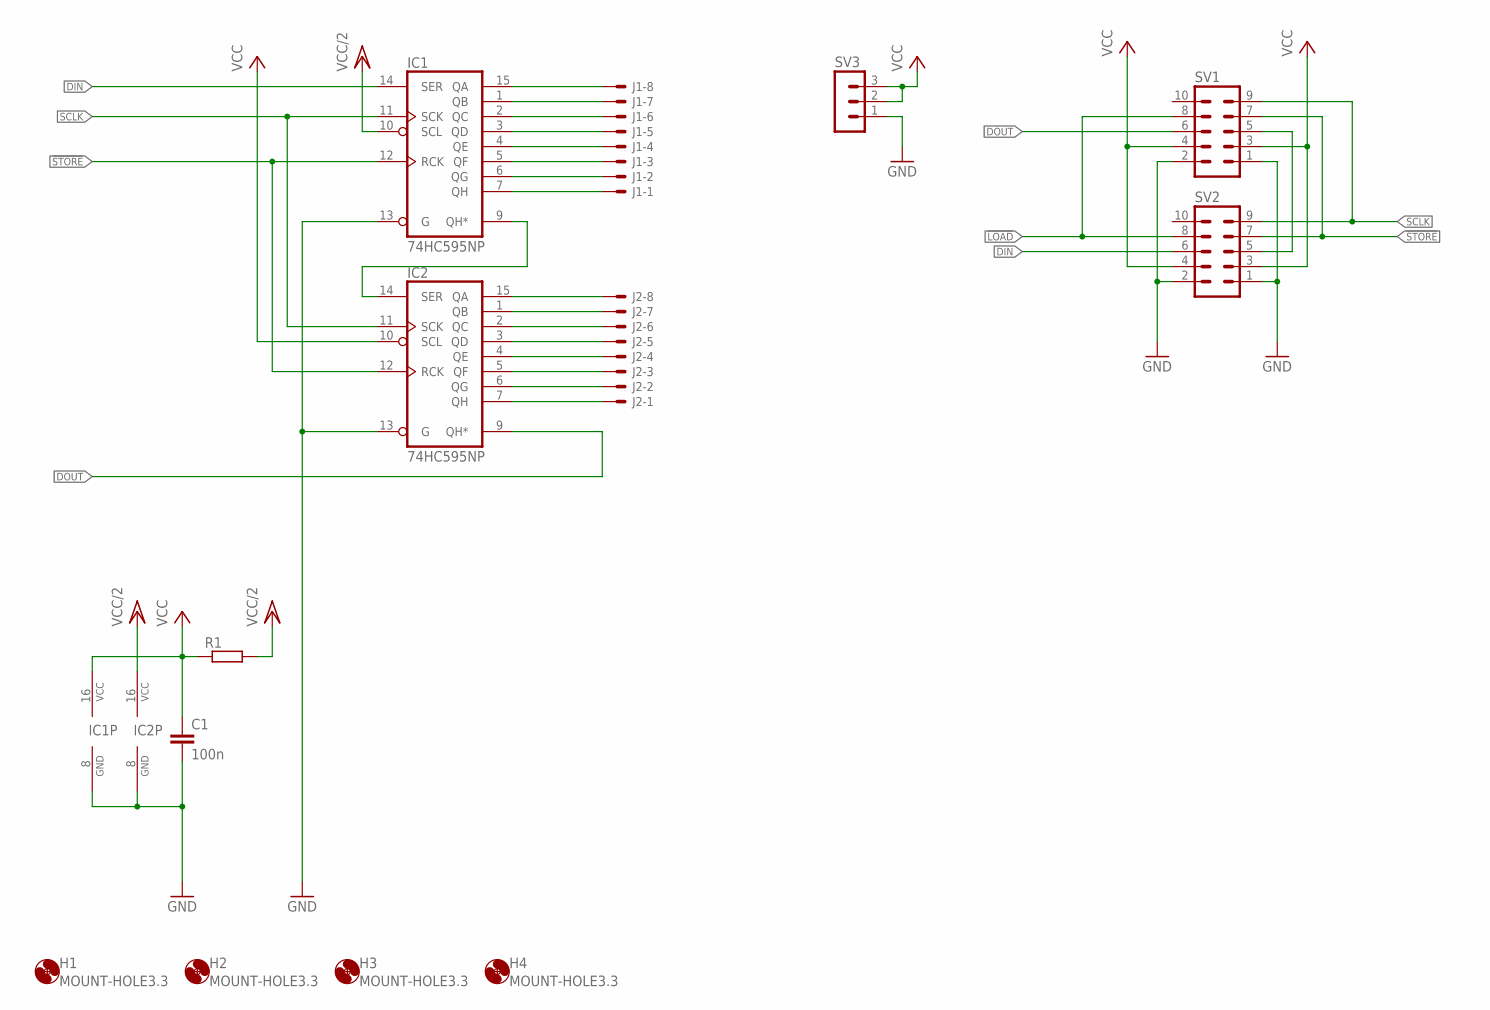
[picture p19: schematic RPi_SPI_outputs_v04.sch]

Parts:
C1: 100n; C1206
H1, H2, H3, H4: MOUNT-HOLE3.3; 3,3
IC1, IC2: 74HC595NP; SOCKET-16
J1, J2: 22-05-7088-SPEC-08; 7395-08_SPEC
R1: R-EU_R1206; R1206
SV1, SV2: ML10
SV3: MA03-1_NO

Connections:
!LOAD: SV1.8, SV2.8
!STORE: IC1.12 (RCK), IC2.12 (RCK), SV1.7, SV2.7
DIN: IC1.14 (SER), SV2.6
DOUT: IC2.9 (QH*), SV1.6
DRET: SV1.5, SV2.5
GND: C1.2, IC1.8 (GND), IC1.13 (G), IC2.8 (GND), IC2.13 (G), SV1.1, SV1.2, SV2.1, SV2.2, SV3.1
unnamed: IC1.15 (QA), J1.8
unnamed: IC1.1 (QB), J1.7
unnamed: IC1.2 (QC), J1.6
unnamed: IC1.3 (QD), J1.5
unnamed: IC1.4 (QE), J1.4
unnamed: IC1.5 (QF), J1.3
unnamed: IC1.6 (QG), J1.2
unnamed: IC1.7 (QH), J1.1
unnamed: IC2.15 (QA), J2.8
unnamed: IC2.1 (QB), J2.7
unnamed: IC2.2 (QC), J2.6
unnamed: IC2.3 (QD), J2.5
unnamed: IC2.4 (QE), J2.4
unnamed: IC2.5 (QF), J2.3
unnamed: IC2.6 (QG), J2.2
unnamed: IC2.7 (QH), J2.1
unnamed: IC1.9 (QH*), IC2.14 (SER)
SCLK: IC1.11 (SCK), IC2.11 (SCK), SV1.9, SV2.9
VCC: C1.1, IC1.16 (VCC), IC2.10 (SCL), R1.1, SV1.3, SV1.4, SV2.3, SV2.4, SV3.2, SV3.3
VCC/2: IC1.10 (SCL), IC2.16 (VCC), R1.2

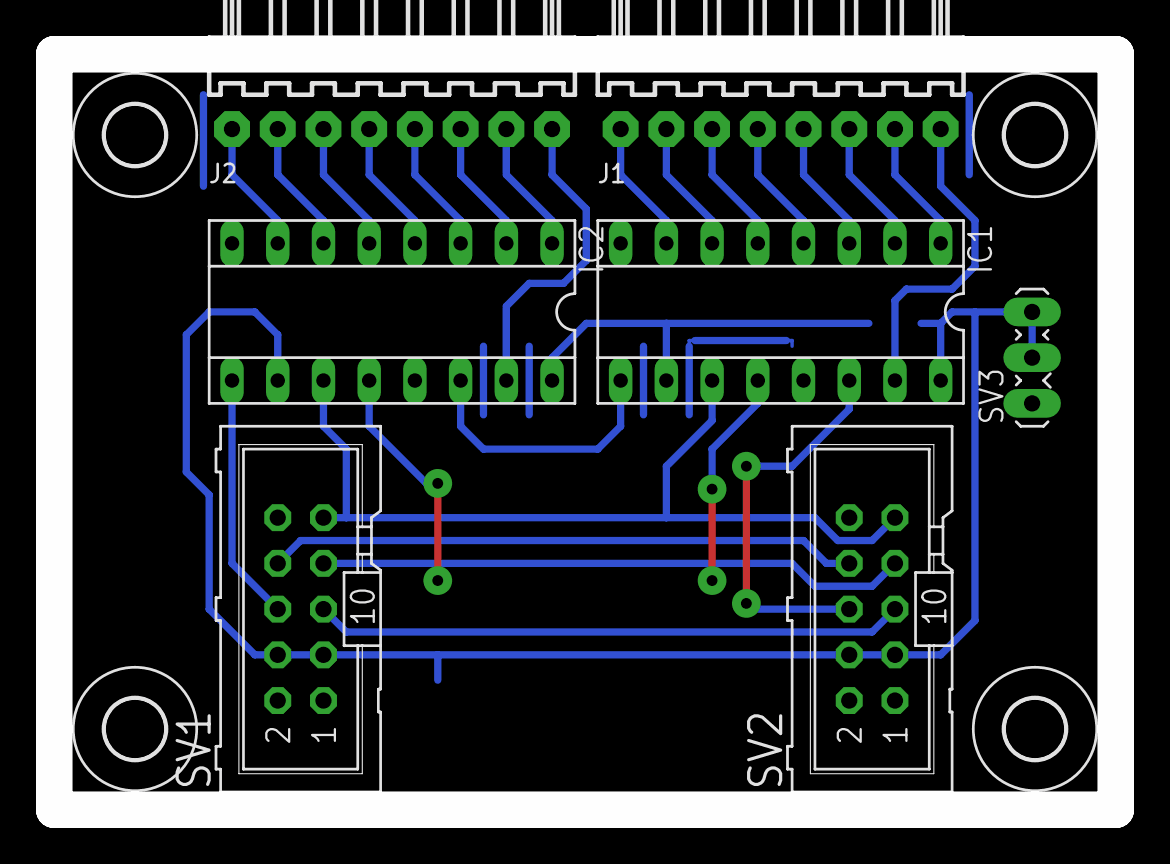
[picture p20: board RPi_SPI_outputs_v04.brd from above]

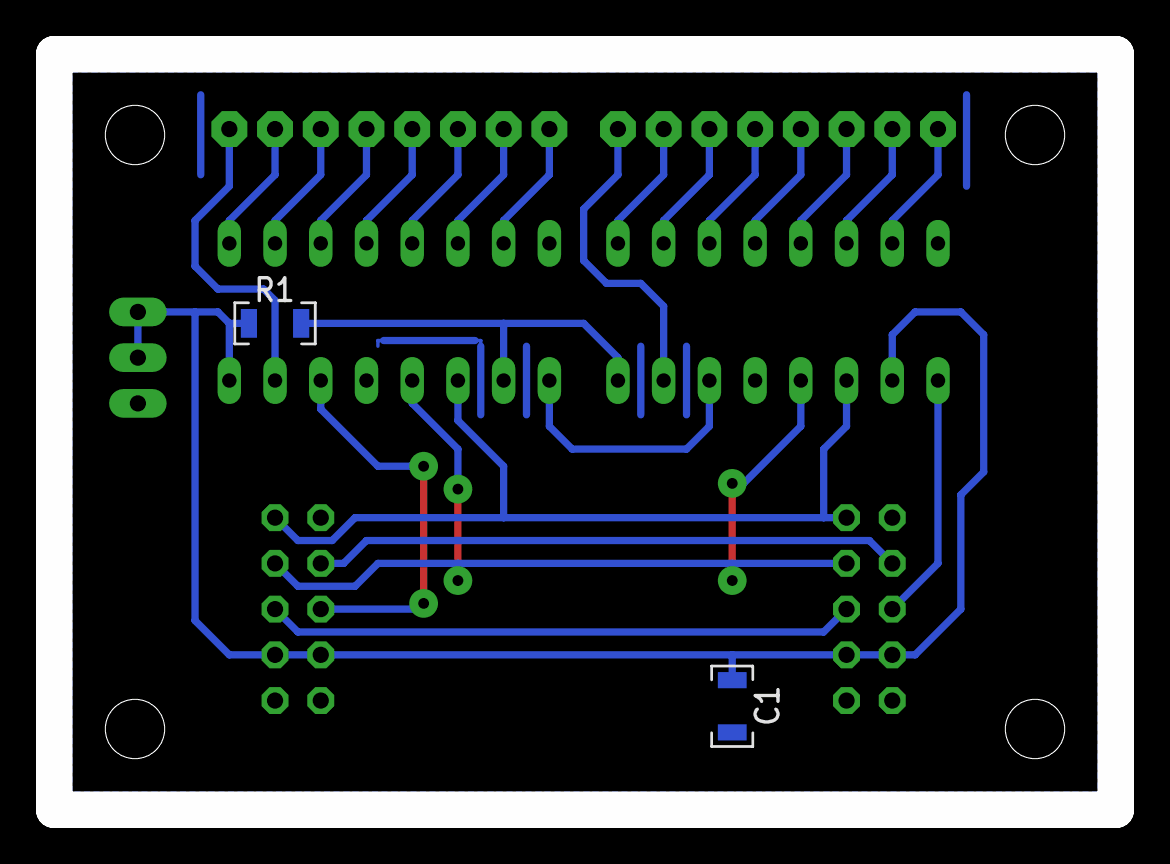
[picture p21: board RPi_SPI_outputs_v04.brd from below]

Board: 2 copper layers, 59.0 x 42.0 mm, 13 parts (2 on the bottom side), 26 nets.

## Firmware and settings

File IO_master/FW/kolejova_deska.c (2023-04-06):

/*
 * BR101
 *
 * Created: 15.09.2022
 *  Author: Michal
 *
 * Sablik pult
 * 
 */

#include "inc/common_defs.h"
#include <avr/io.h>
#include "inc/defines.h"
#include <avr/interrupt.h>
#include "inc/timer.h"
#include "inc/inputs.h"
#include "inc/xpressnet.h"
#include "inc/logic.h"
#include "inc/xn_accessory.h"
#include "inc/sSPI.h"

#include <util/delay.h>

// DCC_dec need Timer2 and one of INT

#include <util/delay.h>
volatile byte timer0_flag = 0; // T = 0.1ms
volatile byte timer1_flag = 0; // T = 10ms


//----------------------------------------------------------
ISR(INT0_vect) {
  //RS_ISR_int();
}

//----------------------------------------------------------
ISR(INT1_vect) {
  // sei();
  //DCC_ISR_int();
}

//----------------------------------------------------------
ISR(TIMER0_OVF_vect) {
  // T = 0.1ms
  timer0_flag = true;
}

//----------------------------------------------------------
ISR(TIMER1_CAPT_vect) {
  // T = 10ms
  timer1_flag = true;
}

//----------------------------------------------------------
/*
ISR(TIMER2_COMPA_vect)
{
  // sei();
  //DCC_ISR_timer2();
}
*/

//----------------------------------------------------------
void process_timer_10Hz(void)
{
  static int postsc_2min = 1000;
  if (timer1_flag) { // T = 10ms
    timer1_flag = false;
    io_timer_10hz();
    logic_timer_10hz();
    uart_update();
    // refresh RS state after 2 minutes
    if (--postsc_2min == 0) {
      postsc_2min = 12000; // 100*60*2
      //RS_forceUpdate();
    }
  } // if timer1_flag
}

//----------------------------------------------------------
void process_timer_7kHz(void)
{
  if (timer0_flag) { // T = 10ms
    timer0_flag = false;
    //RS_ISR_timer_fast();
  }
}

//----------------------------------------------------------
void init(void)
{
  
  io_init();
  DDRD |= BV(PD2); // set XpressNet dir line to output
  PORTD &= ~BV(PD2); // set XPressNet to receiving
  timer_init();
  uart_init(25); // default address
  xnacc_init();
  
  sei();
}

//----------------------------------------------------------
int main(void)
{ 
  //XDIV = 0x80 | 0x77; // low frequency 10 MHz / 10 =  1.000 MHz
  //XDIV = 0x80 | 0x7C; // low frequency 10 MHz /  5 =  2.000 MHz
  
  init();

  while(1) { // mail loop
    process_timer_7kHz();
    process_timer_10Hz();
    io_loop();
    xnacc_loop();
    do_pult_logic();
    //dbg_show_byte(outp[1]);
  }
}

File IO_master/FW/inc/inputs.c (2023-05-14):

/* ========================================================================== */
/*                                                                            */
/*   DCC.h                                                                    */
/*   (c) 2015 Michal Petrilak                                                 */
/*                                                                            */
/*   DCC parser - user functions                                              */
/*                                                                            */
/*   libraly for inputs debounce and hold for specific time                   */
/*                                                                            */
/* ========================================================================== */

#include <avr/io.h>
#include "common_defs.h"
#include "defines.h"
#include "sSPI.h"
#include "inputs.h"

byte inp         [3] = {0,0,0}; // input states for program
byte inp_real    [3] = {0,0,0}; // real states, for debounce
//byte inp_shadow  [3] = {0,0,0};                               // shadow of inp, for calculation
byte outp        [64]; // output states for program
//#define outp_shadow HCdataout
byte inp_last    [3] = {0,0,0}; // last button state, for event generation
byte inp_event_1 [3] = {0,0,0}; // only changed from last time to active state (button pressed)
byte inp_event_0 [3] = {0,0,0}; // only changed from last time to default state
byte inp_cnt [20] = {0,0,0,0,0,0,0,0,0,0,0,0,0,0,0,0,0,0,0,0}; // for debounce - all inputs
void (*pgenerate_events)(void) = 0; // function pointer for callback function GenerateEvents
byte io_flag_10Hz = 0; // private
byte io_blink_10Hz = 1; // public
byte io_blink_2Hz = 1; // public
byte io_blink_10Hz_cnt = 0; // private
byte io_blink_2Hz_cnt = 0; // private

//----------------------------------------------------
static inline void io_out_set(byte seg, byte bit)
{
  HCdataout[seg] |= (1 << bit);
}

//----------------------------------------------------
static inline void io_out_unset(byte seg, byte bit)
{
  HCdataout[seg] &= ~(1 << bit);
}

/*
void dbg_show_byte(byte num)
{
if (num & 0x01) PORTA |= BV(2); else PORTA &= ~BV(2);
if (num & 0x02) PORTF |= BV(6); else PORTF &= ~BV(6);
if (num & 0x04) PORTC |= BV(7); else PORTC &= ~BV(7);
if (num & 0x08) PORTA |= BV(7); else PORTA &= ~BV(7);
if (num & 0x10) PORTC |= BV(5); else PORTC &= ~BV(5);
if (num & 0x20) PORTC |= BV(4); else PORTC &= ~BV(4);
if (num & 0x40) PORTG |= BV(1); else PORTG &= ~BV(1);
if (num & 0x80) PORTC |= BV(0); else PORTC &= ~BV(0);
}
*/

byte dbg_outs[8] = {16,19,17,18,46,45,47,48};

void dbg_show_byte(byte val)
{
  byte i;
  byte num;
  byte pt_seg, pt_b;
  
  for(i=0; i<8; i++) {
    num = dbg_outs[i];
    pt_seg = (num >> 3);     // byte pointer
    pt_b   = 7-(num & 0x07); // bit pointer
    if (val & (1 << i)) {
      io_out_set(pt_seg, pt_b);
    } else {
      io_out_unset(pt_seg, pt_b);
    }
      
  }
}

//----------------------------------------------------
void io_init(void)
{
  // pullups
  PORTB = 0b00000000;
  PORTC = 0b00011000;
  PORTD = 0b00000000;
  
  // smìry pinù
  DDRB = 0b00001000;
  DDRC = 0b00111010; // SPI
  DDRD = 0b00000100; // serial
  
  outp[0] = 0;
  outp[1] = 0;
  outp[2] = 0;
  outp[3] = 0;
  outp[4] = 0;
  outp[5] = 0;
  
  // MOSI
  // MISO
  // SCK
  // LOAD
  // STORE
}

//----------------------------------------------------
byte io_get_state(byte num)
{
  byte pt_seg, pt_b;

  pt_seg = num >> 3;   // byte pointer
  pt_b   = num & 0x07; // bit  pointer

  return ((inp[pt_seg]      >> pt_b) & 1);
}

//----------------------------------------------------
byte io_get_change_on(word num)
{
  byte pt_seg, pt_b;
  byte ret;

  pt_seg = num >> 3;   // byte pointer
  pt_b   = num & 0x07; // bit  pointer
  ret = 0;
  if ((inp_event_1[pt_seg]  >> pt_b) & 1) {
    inp_event_1[pt_seg] &= ~(1 << pt_b); // clear flag
    ret = 1;
  }
  return (ret);
}

//----------------------------------------------------
byte io_get_change_off(word num)
{
  byte pt_seg, pt_b;
  byte ret;

  pt_seg = num >> 3;   // byte pointer
  pt_b   = num & 0x07; // bit  pointer
  ret = 0;
  if ((inp_event_0[pt_seg]  >> pt_b) & 1) {
    inp_event_0[pt_seg] &= ~(1 << pt_b); // clear flag
    ret = 1;
  }
  return (ret);
}

//----------------------------------------------------
void io_set_state(byte num, byte val)
{
  outp[num] = val;
}

//----------------------------------------------------
void io_get_real_state(byte num)
{
  //read all inputs
  
//#define ifsetbit(cond, seg, bit) if (cond) inp_real[seg] |= (1 << bit); else inp_real[seg] &= ~(1 << bit)
#define ifsetbit(port, pin, seg, bit) if ((~PIN##port) & (1 << pin)) inp_real[seg] |= (1 << bit); else inp_real[seg] &= ~(1 << bit)

}

//----------------------------------------------------
void io_debounce_single(byte num, byte debounce_num)
{
  byte but_re, but; // temporary variables
  byte pt_seg, pt_b;

  pt_seg = num >> 3;   // byte pointer
  pt_b   = num & 0x07; // bit  pointer
  but_re = (inp_real[pt_seg] >> pt_b) & 1;
  but    = (inp[pt_seg]      >> pt_b) & 1;

  if (but != but_re) {
    // input is in different state - wait some time
    inp_cnt[num]++;
    if (but_re) {
      debounce_num = 9;
    }
    if (inp_cnt[num] >= debounce_num) {
      // reflect real state to shadow registers
      if (but_re) {
        inp[pt_seg] |=  (1 << pt_b);
       } else {
        inp[pt_seg] &= ~(1 << pt_b);
      }
    }
   } else {
    // input is in same state
    inp_cnt[num] = 0;
  }
}

//----------------------------------------------------
void io_calculate_output(byte num)
{
  byte val;
  byte pt_seg, pt_b;

  pt_seg = (num >> 3);     // byte pointer
  pt_b   = 7-(num & 0x07); // bit pointer
  
  val = outp[num] & 3;

  switch(val) {
    case 0: // off
	  io_out_unset(pt_seg, pt_b);
      break;
    case 1: // on
	  io_out_set(pt_seg, pt_b);
      break;

    case 2: // blink 2 Hz
      if (io_blink_2Hz) {
        io_out_set(pt_seg, pt_b);
       } else {
        io_out_unset(pt_seg, pt_b);
      }
      break;

    case 3: // blink 10 Hz
      if (io_blink_10Hz) {
        io_out_set(pt_seg, pt_b);
       } else {
        io_out_unset(pt_seg, pt_b);
      }
      break;

    default:
      break;
  }
}
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

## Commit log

2023-04-06 initial commit
    working state
    [IO_master_nano.brd, IO_master_nano.csv, IO_master_nano.sch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]
2023-05-14 funkci verze
    vsechny vstupy prirazeny spravne
    [mapa_vstupů_výstupů.xlsx]
2023-06-10 Po startu pustit vsechna tlacitka
    A uprava excelu se vestupy/vystupy
    [mapa_vstupů_výstupů.xlsx]
2023-06-10 opraveny fuses na funkcni
